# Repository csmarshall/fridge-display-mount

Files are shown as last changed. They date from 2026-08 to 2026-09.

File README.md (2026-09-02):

# fridge-display-mount

One display, one fridge, **three ways to hold up one plate**. A Waveshare 23.8 in FHD touch
monitor on the side panel of a Samsung RS23A500ASR counter-depth refrigerator, running a
household chore board. Parametric generators, validated cut files, and the sheets that explain
every decision, published at <https://csmarshall.github.io/fridge-display-mount/>.

Human-crafted and AI-assisted, human-directed: every dimension, constraint and trade-off here was
reviewed and decided by a human; the code was written with AI as a power tool.

| # | design | page | where in the repo |
|---|---|---|---|
| 1 | **The hook** — a bent plate over the fridge top, held flat by magnets. Finished, quoted, tagged `hook-final` | `hook.html` | repo root |
| 2 | **The clamped strut** — two slotted struts to the floor, clamped top and bottom, no magnets. Standalone fallback | `clamp.html` | `strut/` |
| 3 | **The hook, with optional strut** — design 1's plate cut thinner with four strut holes, so design 2's feet can be bolted on later without recutting. **Being ordered** | `index.html` | `strut/hybrid*.py`; the plate comes from the root generator |
| 4 | **The hook in stock aluminium** — hand-drilled. Validated, cheapest, and **rejected**: not a build the owner wants to do. Kept for the record | `angle.html` | `angle/` |

An engineer's guided read of designs 1 to 3, with the questions we want answered, is `review.html`.

`strut/` was its own repository until 2026-09-02 and was merged here with its history, because
design 3's plate is generated by the root generator and two repos meant two homes for one fact.

## The load path, in one line each

1. The arm **bears** on the fridge top and carries all the weight; the magnets only hold the
   plate flat.
2. The **floor** carries the weight; the clamps hold the struts in; nothing is fixed to the
   building, ever.
3. Design 1 as bought. If it proves too lively, two struts through the plate onto design 2's feet
   and lower clamp, and the magnets come off.

## Quick start

```bash
python3 -m venv .venv && .venv/bin/pip install ezdxf gmsh scikit-fem numpy scipy meshio
.venv/bin/python generate_bracket.py            # design 1: bracket_flat.dxf + preview + params
.venv/bin/python audit_dxf.py                   # acceptance test — run after EVERY generation
( cd strut && ../.venv/bin/python generate_hybrid.py )   # design 3's plate, via the root generator, audited
( cd angle && ../.venv/bin/python angle.py && ../.venv/bin/python angle_sheets.py )   # design 4: validate, templates, sheets
.venv/bin/python console_build.py               # index.html, hook.html, clamp.html, angle.html
.venv/bin/python review_build.py                # review.html, the guided read for an outside engineer
./publish.sh --check                            # everything above plus every sheet; pushes nothing
./publish.sh                                    # same, then push main and gh-pages
```

Every generator **validates before it writes** and exits non-zero having written nothing if any
check fails. That is deliberate: a silently-wrong cut file costs real money.

## What is here

| | |
|---|---|
| `generate_bracket.py` | design 1's generator. Formed dimensions in, flat pattern out. `--strut-bolts` adds design 3's holes |
| `audit_dxf.py` | independent acceptance test against any written DXF and its params JSON |
| `bracket_flat.dxf` | design 1's upload file — mm, layer 0, closed contours, one dashed bend line |
| `strut/dxf/H_hook_plate.dxf` | **design 3's upload file**, made by the root generator, audited |
| `strut/dxf/{A_clamp_bar,B_foot,C_plate,D_backing_strip}.dxf` | design 2's cut parts |
| `plate_fea.py` | finite-element plate check (gmsh + scikit-fem) of the body plate under a touch press |
| `console_build.py` | builds the three pages from one model — decisions, checklist, numbers, prices, every sheet |
| `publish.sh` | rebuild, validate, push `main` and the `gh-pages` branch GitHub Pages serves |
| `docs/` | design 1's brief, price study, review notes, vendor reference drawings |
| `strut/BRIEF.md`, `strut/reference/` | design 2's brief and its evidence (strut channel, SendCutSend PDFs) |
| `CLAUDE.md` | every design invariant, all three designs. Read it before changing anything |

Study scripts (`*_sweep.py`, `*_compare.py`, `*_explainer.py`, `*_study.py`) each answer one
question and write one SVG. `strut/clamp_sheets.py`, `strut/package.py` and
`strut/hybrid_sketch.py` do the same for designs 2 and 3; run them from inside `strut/`.

## House rules that bit us

- **No drifting constants.** If a value is derivable, derive it. Hardcoded numbers here have gone
  stale more than once — a magnet total, a detach table, a pad rule, a bend deduction — each time
  silently.
- **One home per fact.** The magnet height once appeared as 11.5, 12 and 13 mm on three drawings;
  the bend deduction lived in two repos with two values.
- **CLI flags may only turn things off.** `x = not args.no_x` silently overrode dataclass defaults
  and shipped duplicate holes into a cut file.
- **Render it and look at it.** Layout cannot be reasoned about.

## Status

Not yet ordered. Design 3's plate needs a re-quote (the last quote was on an earlier drawing), and
the measurements on the index page's "Before ordering" list are still open. Prices are dated
observations, not derived values.

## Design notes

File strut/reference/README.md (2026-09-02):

# reference/

Everything here is EVIDENCE, not opinion. If a number in the design contradicts something in this
directory, the file wins until someone re-verifies it.

## The appliance

(The Samsung spec sheet and both Waveshare dimension drawings now live once, in
`../../docs/reference/`; the copies that used to be here were byte-identical and were removed on
the 2026-09-02 merge.)

- **`samsung-RS23A500ASR-specsheet.pdf`** — the fridge. Case 35 7/8 × 68 5/8 × 24 in
  (911.2 × **1743.1** × **609.6 mm**), 229 lb, counter-depth. The height that matters is the CASE
  height, not the height over the hinge covers.

## The display

- **`waveshare-23.8-dimension-drawing.jpg`** — the one being mounted. 555.23 × 324.65 × 18 mm
  panel, plus a **25 mm raised rear box** (260 × 134, centred) carrying the VESA 100 pattern, so
  overall depth is 43 mm. 3.94 kg. The Pi 5 fan/GPIO opening is in the rear box FACE at a
  **~82 mm radius** (fan, ~30 dia) and **~107 mm** (GPIO slot), both SCALED off the drawing;
  the hook's windows sit at 87.5, an average — do not blank either off.
- **`waveshare-27-dimension-drawing.jpg`** — the 27 in shares the same rear box, VESA and depth
  profile. Only the panel size and mass differ (629.62 × 367.40, 4.92 kg).

## The strut

- **`strut-channel-3310T791.md`** — the chosen channel, transcribed from McMaster because their
  page renders nothing to a bot. Dimensions, the whole price ladder, and **derived** section
  properties with the assumption that produced them stated.

## The fabricator

- **`sendcutsend-mild-steel.pdf`** — material and thickness range.
- **`sendcutsend-bending-guidelines.pdf`** — bend radius, minimum flange, die width, feature
  keep-out from the bend line. The bent foot lives or dies by this document.
- **`sendcutsend-powder-coating.pdf`** — the 15 colours and the part-size limits. **Textured
  Black** was chosen for the previous design because the fridge's side panel is dark and matte.

## Inherited from the hook design — the reasoning, not the geometry

These four carry work that stays true regardless of load path.

- **`inherited-magnet_primer.pdf`** — why a 175 lb magnet delivers 12 lb where it counts. Pull vs
  shear vs peel, the derate chain, and the arithmetic for what magnet-only would actually need.
  **Read this before resizing the magnets.**
- **`inherited-fastener_matrix.pdf`** — all 39 nut × washer × threadlocker permutations against a
  fixed 1/2 in stud, with part numbers. If the magnet changes, the stud may change and this whole
  sheet has to be recomputed — but the METHOD transfers directly.
- **`inherited-bracket_preview.pdf`** — the plate as built: 310 × 310, VESA 100 plus MIS-E/MIS-F
  spare patterns, vent windows on an 87.5 mm radius, cable slots, magnet holes at 246 mm.
- **`inherited-channel_concept.pdf`** — the concept sheet that led to this project, including the
  wedge arithmetic and the numbers the strut design starts from.
- **`inherited-price-study.md`** — the material/thickness price ladder, and why 0.187 in mild
  steel beat aluminium and stainless.
- **`inherited-hook-BOM.md`** — the previous BOM, with sourced part numbers for magnets, nuts,
  washers, threadlocker and foam. Several lines transfer unchanged; the magnet line is the one
  deliberately being revisited.

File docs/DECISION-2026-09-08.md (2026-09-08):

# Decision — 2026-09-08: order design 3, phase 1, today

Charles: "I really want to get this built, but I am tired of fighting this, I need a comprehensive
review and decision today." This is that review and that decision. Everything below is on the
published sheets; nothing here is a new number.

## The decision

**Order the hook plate at 0.119 in with the strut holes (design 3, phase 1) from SendCutSend, and
eight K&J MM-C-32 magnets. Nothing else is cut. No struts, no clamp parts, no floor hardware.**

| line | what | price | source |
|---|---|---|---|
| plate | `strut/dxf/H_hook_plate.dxf`, A36/1008 0.119 in CRS, 1 bend 90 deg, black powder coat | $187.20 | SendCutSend live 2026-09-02 |
| magnets | 8 x K&J MM-C-32, O32 x 8 mm N38, M6 male stud, 75 lb rated | $61.12 | K&J 2026-09-02 |
| hardware | 8 x M6 thin nyloc (DIN 985 low), 8 x M6 fender washer O18, 4 x M4 spacer 10 mm, 4 x M4 low-head screw, 5/16 in neoprene foam strip, VELCRO ONE-WRAP 1/2 in | ~$50, only the VELCRO priced ($31.25) | hardware store / McMaster |
| **phase 1 total** | | **~$280 + display** | `prices.py` |

The strut kit ($207.48) exists as a later add-on through holes already in the plate. Do not buy
it now; the hook is the design, the kit is the insurance.

## Why this and not the others

- **Design 1 (0.187 in):** $10 more, 2.1 kg heavier, and it has no strut holes so the fallback is
  a recut. Its stiffness advantage (0.022 vs 0.085 mm at the screen edge under a 5 lb press) is
  below anything a finger notices. Nothing else differs. `gauge_magnet_matrix.svg`.
- **Design 2 (struts + clamp):** more parts, floor pads, a clamp under the fridge, and a plate
  that shares nothing with the hook. It is the answer only if the hook fails in use, and design 3
  already carries that answer in four holes. `clamp.html`.
- **Design 4 (stock aluminium):** rejected 2026-09-02, hand drilling.
- **Aluminium plate at SendCutSend:** cheaper on the 2026-08-25 cut-only sweep, but flex is 3x
  steel's at the same gauge, no live quote on the real file, and no reason to reopen the material
  when the steel plate is $187.
- **OSH Cut instead of SendCutSend:** $204.26 coated, $17 more. Their standby tier at $60.93 is
  bent and bare, needs the flat regenerated for their bend table, and you keep the coat. Not
  worth a second vendor flow. `vendors.svg`.
- **Other magnets:** 8 x MM-C-32 is the cheapest set to 6x on a 20 lb grab using the eight
  positions the plate has, on every gauge. Bigger magnets only add cost; smaller ones need four
  holes that are not cut. `magnet_economics.svg`, `gauge_magnet_matrix.svg`.

## What is still unmeasured, and why none of it changes the cut file

| item | status | what it affects | how it is closed |
|---|---|---|---|
| hinge-cover window 406 vs 400 mm | two readings | where the arm lands | the plate is not pinned to the case centre; set it 10-20 mm rearward at install. The cover also lifts off. Nothing to recut |
| Pi fan vs vent window, 3.5 mm overlap | scaled off a drawing, +/-5 mm | cooling | windows sit on R87.5 so one covers the fan in every rotation; the 10 mm spacers keep an air channel regardless. Measure the box when the display arrives |
| MM-C-32 stud length | ESTIMATE 10 mm; K&J does not publish it | nut choice only | **order the magnets first**, measure the stud. Stack needs ~8.5 mm (3.0 plate + 1.5 washer + ~4 thin nyloc). Short stud: drop the washer or use a jam nut. The plate hole (O6.5) is right either way |
| M6 part numbers | NOT VERIFIED | nothing | any DIN 985 low nut and DIN 9021 washer in M6 |
| 5/16 in foam | unsourced | pad rule | 7.94 mm against an 8 mm standoff is -0.06, in band. Neoprene sheet or strip, adhesive-backed |
| case height 1743.1 mm | published, not measured | screen height by the same error | irrelevant at +/-10 mm; the neck is cut to the published figure |
| VESA insert depth | unmeasured | M4 screw length | buy screws after the display is in hand |
| PSU wattage | confirm in box | Pi headroom | Mean Well GST90A12 $29.50 if it is 60 W |

The clamp DXFs still need re-upload after the bend-deduction correction. That is phase 2 work
and gates nothing today.

## Order sequence

1. SendCutSend: upload `strut/dxf/H_hook_plate.dxf`, mm, A36/1008 0.119 in CRS, Bending 90 deg
   (the dashed line is read as 1 bend), Deburring, Powder Coating black. $187.20, coated arrival
   about six business days. Longest lead, so first.
2. K&J: 8 x MM-C-32. Measure the stud when they land.
3. Display + PSU if not already bought ($387.01).
4. Hardware after the magnets: nuts, washers, spacers, screws, foam, VELCRO.

## What stays open in the tracker

Issues #1, #2, #3, #5 are hygiene and do not gate the order. #4 is the list above; close its
items as the parts arrive.

## Addendum, same day: exact costs, the gauge question, the magnet band

Charles asked for exact costs, "the cheapest material that can be the thickest and still be powder
coated and bent", and magnets that are "the cheapest but reliably secure", where reliable means
"it takes effort to move it but it's not impossible".

**Exact costs, phase 1, every line priced (`prices.py`, 2026-09-08):**

| line | price | source |
|---|---|---|
| plate, 0.119 in CRS, bent, coated | $187.20 | SendCutSend live |
| 8 x MM-C-32 at the 5-9 break | $58.48 | K&J |
| 8 x M6 A2 jam nyloc | $2.00 | BoltsandNuts |
| 8 x M6 x 18 x 1.7 fender washer | $1.60 | BoltsandNuts |
| 4 x M4 x 16 button head | $0.56 | BoltsandNuts |
| 4 x RAF M0599-4-AL spacer 10 mm | $3.12 | Newark (snippet) |
| 5/16 x 3/4 in x 10 ft neoprene strip | $50.40 | Fix Supply |
| VELCRO ONE-WRAP roll | $31.25 | McMaster |
| **phase 1** | **$334.61** | |

The plate at 0.187 in instead adds $12.70 ($199.90).

**The gauge question (`gauge_magnet_matrix.svg`, live sweep of every bendable gauge on the real file):**
the thickest steel with a published bend spec is 0.187 in HRPO at $199.90, and hot-rolled makes it
CHEAPER than 0.135 in CRS ($235.83). It is 4x stiffer than 0.119 in (0.022 vs 0.085 mm at the screen
edge) for $12.70 and 2.1 kg. Aluminium at 0.100 or 0.125 in is the cheapest bendable, coatable plate
($159) but flexes 2.5-5x more than 0.119 in steel; aluminium at 0.187 in costs $233. The plate with
strut holes was regenerated at 0.187 in (`strut/dxf/H_hook_plate_187.dxf`, audited 15/15, neck 78x,
body 56x). **Recommendation: 0.187 in HRPO with the strut holes, $199.90.** The one cost is the nut
stack: a 10 mm stud with a 4.75 mm plate, 1.7 mm washer and a ~4 mm jam nut is at the limit, and the
K&J drawing gives the stud as 10 +/-2.5 mm. Order the magnets first; if the stud measures short, drop
the washer or use a 3 mm M6 jam nut. Nothing cut changes.

**The magnet band (`removability.svg`):** against estimated human forces (bump 20 lb, one hand 45 lb,
two hands 100 lb), the band is "slide resistance at least 1.5x a bump, lift-off within two hands".
4 x MM-C-32 is under the bump margin (21 lb). 6 x is in the band (slide 32 lb, lift 50 lb). 8 x is in
the band (slide 42 lb, lift 61 lb, 65 lb on the heavier plate). **Recommendation: buy 8, fit 8.** The
35 % derate is the largest unknown and it flatters the magnets; 8 keeps margin against it. If the
mount fights you when repositioning, take two out — a two-minute change, no parts to buy.

**Stud length is now verified:** K&J drawing MM-C-32.pdf, overall 18 mm, body 8 mm, stud 10 +/-2.5 mm.

## FINAL — Charles, 2026-09-08 12:45

**Plate: 0.187 in HRPO with strut holes, $199.90. Magnets: buy 8 x MM-C-32, fit 8.** Phase 1 total
$347.31, every line priced. The design's cut file `strut/dxf/H_hook_plate.dxf` is now that plate
(310 x 738.81 mm flat, 35 holes, 14 windows, audited 15/15). Order sequence unchanged: plate first,
magnets second, measure the stud when they land, then hardware.

## Addendum 2, same day: one vendor

Charles asked whether magnets from both vendors had been compared with shipping. They had not.
Done: K&J MM-C-32 $58.48 + $7 postage against McMaster 3506K64 $76.96 folded into the one McMaster
shipment that already carries the foam, grip sheet and screws. Net about a wash, four orders become
one. **Decided: McMaster only.** The 3506K64 is the same disc and rating; its 5/16 in height matches
the 5/16 in pad exactly and its 3/8 in stud is a read figure, so the nut stack is settled (thin 1/4-20
jam nut 91847A029, no washer). Hole opened to O7.0 for the 1/4 in stud; the plate file regenerated and
audited. Every hook-hardware line is now a McMaster part number read logged in on 2026-09-08.

**The McMaster order:** 8 x 3506K64, 91847A029 jam nuts (100), 92095A194 M4 x 16 button heads (100),
4 x 94469A046 spacers, 93375K431 neoprene 1/4 x 12 x 12 (laminated under the EPDM to make 5/16), 3727T47 crisscross EPDM 1/16 x 12 x 12,
and optionally 1621N71 grip sheet to slide-test against the EPDM. VELCRO from anywhere.

Foam corrected the same afternoon: the 5/16 in strip was $45.63 for a fifth of a roll; a 1/4 in 12 x 12 sheet under the EPDM skin makes the same 7.94 mm for $23.87.

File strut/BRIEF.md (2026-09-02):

# Fridge-Side Display Mount — STRUT REVISION

Mount a Waveshare 23.8 in FHD touch monitor on the **left side panel** (facing the fridge) of a
Samsung RS23A500ASR counter-depth side-by-side, at a comfortable standing touch height, to run a
household chore board.

**This supersedes a completed hook design.** That design is finished, validated and quoted — it is
not abandoned for being wrong. It is superseded because this one is height-adjustable after the
fact, does not depend on the fridge top at all, and puts the load into the floor. The hook repo is
tagged and kept; see "What came before".

---

## 1. The design, as decided

A **frame**, not a bracket:

```
        display  -> plate -> two struts -> bent foot -> FLOOR
                       |          |
                    (VESA)    magnets to the side panel, in PULL
```

- **Two 6 ft slotted struts**, McMaster **3310T791**, black powder-coated low-profile channel,
  running vertically up the side panel at **246 mm centres**.
- **A bent foot** — one manufactured part — that ties both strut bases together, slides under the
  fridge, and is **wedged** so the appliance's own weight bears on it.
- **A plate** across the struts carrying the display on VESA 100.
- **Magnets** through the strut webs onto the side panel.

### The strut orientation is forced, and it is the good one

Flat back against the panel, slots facing the room. It is the only orientation where a magnet can
bear on the channel, and it gives a wide flat bearing. The cost is that the channel's WEAK bending
axis ends up in the pull direction — which does not matter, because the magnets carry that load.

### The plate should bolt on unmodified if it can

The hook design's plate is 310 × 310 with four Ø8.5 magnet holes at **246 mm centres**, which is
exactly the strut spacing, and Ø8.5 clears a 5/16 channel bolt. Reusing it unchanged is the
cheapest good outcome. **Verify this rather than assuming it** — the previous plate's holes were
sized for a magnet stud, not a channel bolt, and the loads are different now.

---

## 2. What is settled, and the numbers behind it

All computed against a 5 lb press at the screen centre (1331 mm), which is the governing everyday
load — not the display's weight.

| | |
|---|---|
| Overturning at the base | 29.6 N·m |
| Foot strength, 310 mm wide, 0.187 in | 25 MPa vs 248 yield — **SF 10** |
| Strut strength, pull direction | 41 MPa — **SF 6.1** |
| Torsion, edge press, over 246 mm spacing | **3.3 lb per strut** |
| Magnets propping at screen height | **5 lb of PULL shared over 4** — 1.25 lb each |
| Sway if the magnets were absent | **4.7 mm** at the screen |

**The magnets provide STIFFNESS, the foot provides STABILITY, and they are not interchangeable.**
Tying the strut bases does nothing for sway, because the pull load is out of the frame's plane.

### The wedge

The foot slides under the fridge and is wedged (wood shims or similar) so appliance weight lands
on it. What that has to achieve:

| wedge inboard | weight needed on the foot | as a share of the fridge |
|---|---|---|
| 100 mm | 66.6 lb | 29 % |
| 150 mm | 44.4 lb | 19 % |
| **200 mm** | **33.3 lb** | **15 %** |
| 250 mm | 26.6 lb | 12 % |

It is a modest fraction, and further inboard is cheaper.

**DECIDED 2026-08-29: do not chase that load transfer.** The wedge is driven SNUG only — enough to
close the gap, no more. Nothing is taken off the fridge's levelling legs and nothing presses hard
on a base pan that was not designed for a point load.

**This changes what the foot is for, and it is a better answer.** A snug wedge does not anchor by
weight; it removes the slack so the tail is CAPTURED. If the frame tries to tip, the tail can only
rise by the wedge clearance before it bears on the underside of the appliance — tipping is arrested
**geometrically**, by a positive stop, not by friction or by transferred weight. That is a
mechanism you can design and inspect, where "how hard someone drove a wedge" is not.

The magnets still carry the working case on their own, in pull, at roughly 49×. The captured tail
is what stops a lurch becoming a topple.

---

## 3. Open — must be resolved on the actual appliance

**Measured 2026-08-29, roughly:** the gap under the side is **10–20 mm**, and **the underside is
NOT flat**. Both change the design — see §3b.

**Still open — need the appliance:**

1. **Whether a 150–250 mm tail fouls anything.** The irregular underside that gives the pad
   something to bear on also gives the tail something to hit: compressor, tubing, insulation,
   cross-members. This sets the tail depth and nothing else can.
2. **Whether there is a downward-facing rib or lip within reach.** If there is, HOOKING it beats
   bearing on it, because a hook has no compliance at all.

**Answered 2026-08-29:**

3. **Wedge pressure — SNUG ONLY.** See above. The foot captures the tail; it does not transfer
   load. Nothing comes off the levelling legs.
4. **Floor — wood, flat enough.** **No levelling adjustment** — the foot stays a simple bent part.
   But it gets a **pad underneath**, and the reason is not the pressure: at under 3 psi nothing is
   being crushed. It is that the foot's **laser-cut edges line-load a floor that is not perfectly
   flat**, that any grit trapped beneath turns the foot into an abrasive, and that this assembly
   sits unmoved for years rather than being shuffled about.

   **The pad has to GRIP as well as protect**, which rules out the obvious choice. Felt is the
   standard furniture answer and it is wrong here — it would let the assembly slide, which is the
   one thing it must not do. Wants a non-marking rubber or EPDM. **Flag:** rubber left in contact
   with a polyurethane wood finish for years can discolour it through plasticizer migration, so
   the compound matters. Not yet sourced.
5. **Pull-out — rare, treat it as a teardown.** Moving the fridge means unwedging and re-seating.
   That permits a deeper tail and a properly fitted wedge rather than something designed to slide
   in and out, and it means the wedge can be shaped for the gap rather than generic.

---

## 3a. CLAMP the struts to the fridge — decided 2026-08-29

Two adjustable L brackets, one near the top of the struts and one near the bottom, each reaching
from the strut onto the fridge with **foam on the face that touches the appliance**. Slide them
along the strut slots until both are engaged, then lock. The struts are then positively clamped
against the side panel.

**This is the strongest version of the design so far, and it is mostly free.**

### What the top bracket actually has to do

It is a RETENTION bracket, not a hook. The foot already carries the weight.

| clamp height | force to hold the top in |
|---|---|
| at the fridge top (1743 mm) | **3.8 lb** |
| lower, at 1500 mm | 4.4 lb |
| lower still, 1200 mm | 5.5 lb |

Compare the hook design's arm, which carried the **entire 24.9 lb** hanging weight, bore on a
sponge pad, and needed a **180 mm reach** purely to land magnets on metal. This bracket carries
nothing. Its reach only has to be enough not to slip off — tens of millimetres.

### What that buys

- **Anti-tip becomes positive and mechanical.** No longer a magnetic duty. The "what if a magnet
  peels" failure mode goes away.
- **The magnets drop to anti-rattle, or go entirely.** They were carrying 5 lb of pull; the clamp
  now does that. At $23.92 each that is **up to $191 off the BOM** — the largest line in it.
- **The hinge cover stops mattering.** A tens-of-mm reach at the rear of a 406 mm clear window is
  not a clearance problem the way a 180 mm arm was.
- **The slots ARE the adjustment.** A 6 ft strut is 1829 mm against a 1743 mm fridge, so it
  already stands 86 mm proud — the top bracket has somewhere to live without extending anything,
  and the clamp is made by sliding the lower bracket up until snug and locking it.

### What it costs

It reintroduces a fridge-top interface, which §1 had listed as something this design escaped.
That is a real give-back — but a light retention bracket with a short reach is a much smaller
commitment than an arm carrying the whole load, and the clear-window measurement that made the
hook work is already in hand.

### The two clamp brackets are ONE part, made twice

Top and bottom are the same L, the lower one flipped. Foam goes on the same face of the part in
both cases — facing down onto the fridge top, facing up against its underside. One DXF, one part
number, quantity two.

Size the part for the BOTTOM's constraint, which is the strict one: it has to enter a 10–20 mm
irregular gap. The top merely rests on a surface and has a 406 mm clear window to live in, so it
is never the binding case.

### The foot and the lower clamp must be SEPARATE parts

They point opposite ways off the same strut — foot outward onto the floor, clamp inward under the
appliance — so they do not conflict. But they cannot be one part, and the reason is mechanical
rather than aesthetic:

**The lower clamp has to slide UP the slot to generate clamp force. The foot has to stay on the
floor.** Combine them and tightening the clamp lifts the foot off the ground, which destroys the
load path you built the foot for.

### Sizing the foot, now that the clamp exists

If the foot had to resist tipping alone, by reaching out into the room:

| outward reach | SF |
|---|---|
| 200 mm | 1.04 |
| 250 mm | 1.30 |
| 300 mm | **1.56** |

About 300 mm gets there unaided — and that is a lot of steel on a kitchen floor, right where
someone walks.

**The clamp removes that requirement.** With anti-tip handled at the top for 3.8 lb, the foot only
has to carry 154 N downward and not rock. Size it for bearing and for not wobbling underfoot, not
for tipping — which means it can be modest, and stay out of the way.

### Open on this

- **How the brackets generate clamp force.** Sliding the lower one up the slot until snug needs no
  extra parts, but it wants drawing before it is believed — this is exactly the kind of thing that
  reads fine in prose and turns out to need a jacking feature once it is drawn.
- **What the bottom bracket engages.** Same 10–20 mm irregular gap as the foot, so probably the
  same conforming-pad answer in a second place.
- **Whether the identical-part idea survives contact with both reaches.** If the bottom is limited
  by fouling and the top by nothing, one length may be wrong for one of them.

---

## 3c. THE ASSEMBLY — decided 2026-08-31

**Two parts, two of each.**

**Part A — the studded clamp (×2, the lower one flipped).** An L: the long leg lies on the fridge
top, or reaches under its base. The short leg runs down (or up) the side. An **ELEVATOR bolt**
through a square hole in the short leg gives the stud — its square shoulder locks in the laser-cut
hole so it cannot spin, which means the bracket stays a pure laser-plus-one-bend part with no
welding and no secondary operation.

**Elevator, not carriage, because the head faces the FRIDGE.** 5/16"-18 elevator: head 30.16 mm
diameter x **2.78 mm** thick and FLAT, against a carriage bolt's 19.81 mm x 5.08 mm dome. At 2.78
the head **hides inside the 3 mm foam and never touches the panel**; a carriage dome stands
**2.08 mm proud** of the same foam and presses a hard point on appliance sheet. It also spreads
over 715 mm2 instead of 308 — 2.3x the bearing.

The square neck is 8.38 mm across x 4.83 mm long, so it passes **1.80 mm beyond** a 3.02 mm clamp
leg: **the foot's slot has to clear 8.38 mm, not just the 7.94 mm shank.**

**The nut goes INSIDE the channel, bearing on the strut's back web.** The slots are in that web,
so the bolt passes clamp 3.02 + foot 3.02 + web 1.78 = **7.83 mm of material**, plus the nut. A
3/4 in bolt would do; 1 in is comfortable.

Running the bolt clean through the channel and nutting it outside the open face would be a much
longer bolt for no reason, and it would put the nut exactly where the **plate's channel nuts have
to live**. The open face stays clear. Foam lines the inside of the L; no steel touches the appliance
anywhere.

**Part B — the slotted foot (×2, one per strut).** Vertical leg carrying an elongated slot for the
stud; horizontal leg bending **outward, into the room**, tucking under the strut so the strut
stands on it. It therefore never touches the floor and needs no separate floor pad.

**REVISED 2026-08-31: one foot per strut, not two back to back.** The inboard foot was removed
because it was doing nothing the rest of the assembly was not already doing:

| what it might have done | what actually does it |
|---|---|
| resist tipping outward | the outboard foot |
| resist tipping inward | **the fridge** — it is right there |
| anti-lift under the appliance | the lower CLAMP, which was always its job |

Removing it takes one layer out of the stud stack: the gap drops 12.07 → **9.05 mm**, the display
face comes in to **75.7 mm**, and the top washers halve from 6.05 to **3.02 mm**.

### The stack through the stud, and the washers that make it work

At the base the stud passes clamp leg + foot leg = **6.05 mm** before it reaches the strut. Left
alone that would stand the strut off at the bottom and hard against the panel at the top, so it
would lean.

**Fix: 3.02 mm of washers behind the strut at the top**, replacing the foot leg that is not there.
The strut then sits **~9 mm off the panel, parallel, top and bottom** — and nothing but foam ever
touches the appliance.

### How far the display ends up sticking out

66.7 mm of it is fixed no matter what — strut 20.64 + plate + 25 mm rear box + 18 mm panel. Only
the gap is a variable:

| | gap | display face off the panel |
|---|---|---|
| two feet back to back | 12.07 mm | 78.7 mm |
| **one foot, as built** | **9.05 mm** | **75.7 mm** |
| feet outboard of the strut entirely | 6.02 mm | 72.7 mm |

Standard-height channel instead of low-profile would add **20.6 mm** on top of any of these, which
is why low-profile is a requirement and not a preference. Everything here is well inside the
117 mm the doors project.

### Assembly sequence

1. Bolt the two feet back to back, slots aligned, and stand the struts on the outboard legs.
2. Hook the top clamps over the fridge top; stud through washers and the strut slot; nut loose.
3. Slide the lower clamps **up** their slots until they engage under the appliance; lock.
4. Tighten the top nuts. The struts go into tension between the clamps and the fridge is gripped.

### Sliding along the panel — SOLVED by geometry, not friction

Friction alone gives roughly **15–30 lb** of resistance (foot plus preloaded clamps). Enough for
ordinary use, but not positive location.

**Use the clear window instead.** The hinge cover occupies the front 203 mm of the fridge top and
the measured clear window behind it is **406 mm**. Size the top clamp's long leg to very nearly
fill that window and it is captured front-to-back between the hinge cover and the rear edge — a
geometric stop, using a measurement already in hand, needing no extra feature and no second bend.

---

## 3b. The foot, after the gap was measured

**10–20 mm, and not flat.** Two consequences.

### The wedge is the wrong device — use a conforming pad

A wedge bears on unknown high points of an irregular surface, and at the tight end of the range a
0.187 in foot leaves only 5.25 mm for it, which is a fragile shim needing per-location fitting.

**Use a foam pad on top of the tail instead.** It conforms to whatever is up there, which is
precisely the problem, and it needs no fitting. The obvious objection — that foam is a spring and
therefore not a stop — does not survive the arithmetic. The force is small and the area is large:

| pad | thickness | squash under a tip load | screen movement |
|---|---|---|---|
| 60 × 200 mm | 10 mm | 0.37 mm | **2.5 mm** |
| 80 × 250 mm | 10 mm | 0.22 mm | 1.5 mm |

At design loads it barely moves. It behaves as a stop.

### The one real trap is PRELOAD, and it is a big one

Area multiplies pressure. On a 60 × 200 mm pad of the project's 12-psi-at-25 % neoprene:

| compressed | force pushing UP on the fridge |
|---|---|
| 2 % | 18 lb |
| 10 % | 89 lb |
| 25 % | **223 lb — half the appliance** |
| 50 % | 446 lb — you are lifting it |

**Size the pad to JUST TOUCH.** Do not squeeze it in. Fit it by building up layers until contact,
which is acceptable because moving the fridge is a teardown anyway. Half a percent of strain is
0.3 mm of screen movement — the job needs nothing more than contact.

### Foot thickness: go thinner than the hook's

The foot only sees the full moment as a BACKSTOP, so it does not need SF 10.

| | | |
|---|---|---|
| 0.187 in | SF 9.8 | only 5.25 mm of pad room in a 10 mm gap |
| **0.119 in** | **SF 4.0** | **6.98 mm of pad room** |
| 0.075 in | SF 1.6 | too thin |

**0.119 in** is the balance. Threaded jacking screws were considered and rejected: precise and
adjustable, but they bear on a point of an irregular surface, and conformity is worth more here
than adjustability. Keep them in mind only if a genuinely rigid stop is ever wanted.

---

## 4. The magnet decision — deliberately reopened

The hook design used McMaster **3506K67**: Ø48.02 × 11.51 mm, 175 lb rated, **$23.92 each**, eight
of them — **$191, the largest line in the BOM**.

In this design the demand is **1.25 lb per magnet against 61.2 lb of derated capacity — 49×**.
That is heavily over-specified. **Resize it.** Constraints to respect:

- Derate to **~35 %** of rated pull on 0.6–0.9 mm painted appliance sheet. Vendor ratings assume
  thick steel at zero gap and neither holds here.
- The magnet body height IS the standoff, and it must clear the strut wall (1.78 mm) with enough
  stud left for a nut inside the channel.
- Keeping a **5/16"-18 male stud** would let the whole fastener analysis carry over unchanged
  (`reference/inherited-fastener_matrix.pdf`). A different thread means redoing it.
- Read `reference/inherited-magnet_primer.pdf` first. The physics of why ratings mislead is
  already worked out and it does not need redoing.

---

## 5. Deliverables

Match the previous project's shape — it worked:

| | |
|---|---|
| `generate_foot.py` | parametric generator for the bent foot. Formed dimensions in, flat pattern derived by subtracting the bend deduction. **Validates, then writes; exits non-zero and writes NOTHING on failure.** |
| `foot_flat.dxf` | the upload file. mm, layer 0, closed contours, one dashed bend line |
| `foot_params.json` | machine-readable expected geometry |
| `audit_dxf.py` | acceptance test, run after every generation (copied in, needs re-pointing) |
| `assembly_*.svg` | how it goes together |
| `SENDCUTSEND-ORDER.md` | order config, hole schedule GENERATED from the params, compliance table |
| `BOM.md` | sourced, with part numbers and dates |
| `index.html` | the console page, via `console_build.py` |

---

## 6. Hard-won lessons from the previous project

These cost real time. Do not rediscover them.

- **Never hand-maintain a table that the generator could emit.** The previous order document's
  hole schedule drifted a whole revision and described screws into a thread that did not exist.
- **A flag may only turn something OFF.** Argparse defaults silently overrode dataclass values
  five separate times, once putting duplicate holes 0.02 mm apart into a cut file.
- **Filter `spare` when counting magnets.** Counting holes as fitted magnets produced wrong force
  figures on four different sheets.
- **SVG is XML.** Text emitters must escape `&`, `<`, `>` — one bare `<=` silently destroyed a
  whole document.
- **Emit every leader, rule and dimension BEFORE any text that has to survive them.** The same
  z-order bug appeared in four different sheets; a halo behind text is useless if geometry is
  painted over it afterwards.
- **Derive positions, never fix two things that must stay clear of each other.** Fixing one and
  moving the other into it happened repeatedly.
- **Colour follows the BACKGROUND, not the subject.** The fridge is near-black; anything drawn on
  it needs the light palette, and anything drawn on paper does not.
- **Render and look. Do not reason about layout.** Three consecutive fix passes each repaired
  defects and introduced new ones; only rendering caught it.
- **State provenance.** Mark every number as measured, derived, or estimated. A vendor figure and
  a guess must not wear the same font.

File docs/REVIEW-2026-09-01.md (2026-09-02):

# Project review and gap analysis — 2026-09-01

Scope: both repos (`fridge-display-mount`, the published page, and `fridge-strut-mount`, the
clamp/hybrid generator), read top to bottom against `CLAUDE.md`, `BRIEF.md`, `session-state.md`
and the 2026-08-27 review. Everything below was checked by running it, not by reading prose.

## What was verified working

| Check | Result |
|---|---|
| `generate_bracket.py` + `audit_dxf.py` (hook) | 0 errors, 4 warnings; audit 15/15 ACCEPT |
| All 20 study/sheet scripts in the pages repo | every one exits 0 and reproduces its committed SVG byte-for-byte |
| All 7 scripts in the strut repo | exit 0, SVGs reproduce byte-for-byte |
| 2026-08-27 review items A1–A4, C1–C4, D1–D5 | all closed (order doc rebuilt, BOM item 1 on $197.07, CLAUDE.md §4b/§5/§1.5 fixed, washer 0.060 justified in source, `mu_rubber` renamed, 27in drawing regenerated) |
| `hook-final` tag | present |
| GitHub Pages | live at csmarshall.github.io/fridge-display-mount, built from `gh-pages` |

DXF regeneration is non-deterministic (handles and timestamps), so a DXF diff is never evidence
of a geometry change. The audit is the only test.

## Gaps, ranked

### 1. The published page says the opposite of the current decision
`index.html` "What is being built": *"CURRENT — a clamped strut … there are NO MAGNETS … Work
continues in fridge-strut-mount."* Session state 2026-09-01: the hook is **primary again**, the
clamped strut is the fallback, and a third design (hook plate prepared for struts) is what will
be ordered. Neither `index.html` nor `archive.html` mentions the third design at all (grep for
third/hybrid/contingency: 0 hits in both). `hybrid_overview.svg` / `hybrid_sketch.svg` are
committed but not registered in `console_build.py`. `gh-pages` is at 08-31 18:23, one
decision behind.

### 2. The hybrid plate is 0.119 in, and the reason recorded for that is false in phase 1
`hybrid.py:41`: `plate_t = 0.119 * IN  # was .187 HRPO; the feet take load off the plate`.
The first order is the hook plate ALONE with no feet; the feet are bought only if the arm is too
lively. So in the configuration actually being ordered, a 0.119 in plate carries the full hook
load — the case the hook design settled on 0.187 in for (`thickness_study`, PRICE-STUDY: 0.14 mm
deflection, "feels rigid"). `hybrid.py` has **no stress or deflection check at all**; the hook
generator's neck/body SF checks were not carried over. Strength is almost certainly fine (SF
~25x by t² scaling from the 0.187 figures) but touch-press stiffness drops ~4x (t³) and nobody
has computed it. Either re-run the thickness reasoning at 0.119 and record the result, or go
back to 0.187 and re-quote.

### 3. The strut repo's cut files have no acceptance test
Five DXFs in `dxf/` and `audit_dxf.py` cannot run against any of them: it requires an
expectations JSON and none is written (`generate_parts.py` / `generate_hybrid.py` never emit
one; no `*.json` exists in the repo). BRIEF §5 lists `foot_params.json` and "audit_dxf.py …
needs re-pointing" as deliverables; neither happened. Session state's "audits clean" for
`H_hook_plate.dxf` was an ad-hoc run that cannot be repeated. This repo's own README says a
silently wrong cut file costs real money; the strut repo has exactly that exposure.

### 4. Four generator warnings nobody has acknowledged
`magnet_window_overlap`: all four body magnet discs overlap their vent window by **11.51 mm**
("the magnet face would sit over a hole"). Not mentioned in CLAUDE.md, the order doc, the BOM
or the page. Either it is accepted (magnet face bridges the window, foam still bears) and should
be written down as a decision, or the windows should move. The hook page currently shows the
part as validated without saying it carries warnings.

### 5. Stale text on the CURRENT page's "Before ordering"
- "406 mm clear … against a **190 mm arm width**" — hook text on the clamp page (no arm exists).
- "Pi fan opening is at R87.5 mm" — superseded 08-31 by the two-feature reading (fan ~R82,
  GPIO slot ~R107) that CLAUDE.md records; the page still carries the averaged figure that
  CLAUDE.md explicitly says "hid that the fan is the near one". `reference/README.md` in the
  strut repo says 87.5 too.
- Hinge cover: commit b023977 says "measured at 209.55", CLAUDE.md says "front 203 mm". One
  home per fact — pick one.
- `archive.html` still captions the thickness study "SUPERSEDED" (it is the current build's
  study, aluminium-era caption) — B2/B5 from the last review, half-fixed.

### 6. Documents that describe a repo that no longer exists
- `README.md` title `# fridge-magnet-mount`; says `console_build.py` builds `index.html` as
  "the working surface" (it now builds the clamp page and `archive.html` for the hook); "Four
  measurements gate it" (the page lists three open, one blocked); no mention of the strut repo,
  the archive page, the tag, or how `gh-pages` is published.
- `fridge-strut-mount/START-HERE.md` points at `csmarshall/fridge-magnet-mount` (renamed).
- `fridge-strut-mount/console_build.py` is a stale copy importing a module that is not there
  (session state already says ignore it — delete it).
- `channel_concept.py` writes `channel_concept.svg`, which is untracked and unused (the page uses
  `strut_concept.svg`). Dead script or missing commit.
- `docs/.REVIEW-2026-08-27.md.swp` — vim swap file on disk.

### 7. Process gaps
- **Zero GitHub issues** in either repo. The `feature:/bug:/chore:` queue convention has
  never been exercised here; every loose end lives only in the gitignored session-state.
- **Both repos have one unpushed commit** (c81b898, 67228cf). Pages is manually published
  (no workflow, no script, not documented) and is behind main by one publish.
- **Bend deduction is still K = 0.42 estimate**, not SendCutSend's calculator value, across
  all three designs. CLAUDE.md §4 has said "replace" since 08-24.
- **Six BOM lines in the clamp design are NOT PRICED**; the backing strips cannot be powder
  coated at 20 mm and would be the only bare steel; fit-or-not undecided.
- **The hybrid's strut overlap is luck** (43 mm at exactly 4 ft), already flagged in session
  state but not guarded by an assertion in `hybrid.py` the way `magnet_to_bolt` is.

### 8. Measurements still open before any order
From the page and the briefs, unchanged for a week:
1. Height to the top of the CASE (design assumes Samsung's published 1743 mm) — blocked.
2. Photograph the display's rear box: fan opening position and size (scaled ±5 mm; now gates
   the plate in the clamp design).
3. VESA insert thread depth (sets M4 length).
4. Top corner radius (confirmation only; pad covers to R35).
5. Under the fridge: does a 150–250 mm tail foul anything; is there a rib to hook (clamp design
   only, needs a torch).
6. Bundled PSU wattage vs the 63 W budget (CLAUDE.md §5) — still "confirm in box".

## What I did not change
Nothing in either repo was modified. Generated files were regenerated to check reproducibility
and restored with `git checkout`. The one untracked file I produced (`channel_concept.svg`) was
deleted.

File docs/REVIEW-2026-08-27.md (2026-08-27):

# Package review — 2026-08-27

Four independent reviews (numeric consistency, narrative consistency, visual defects, plus the
magnet-primer build). Findings below are **deduped and merged**; "×2" means two reviewers found
it independently, which raises confidence.

Nothing in this file has been fixed yet unless marked FIXED.

---

## A. Critical — documents that would cause a wrong order

| # | Finding | Where |
|---|---|---|
| A1 ×2 | **The order document is entirely on the superseded 0.119" build.** Thickness, bend deduction (0.1955" vs current 8.19 mm), blanks 687/737, neck 262, spacing 250×240, "two arm magnets", cut ~$87. It also still describes **magnet screws into a female thread** — the magnet is now a male-stud part with no screws at all — and gives the standoff as both "6 mm" and "8 mm" in one section when it is 11.51 mm. It references a file `..._neck260.dxf` that does not exist. | `SENDCUTSEND-ORDER.md` |
| A2 ×2 | **BOM item 1 orders a part that no longer exists**, at 0.119", blank 310×742, **$185.54**, with "4 countersinks" — contradicting this same file's own correction banner and `countersink_vesa: false`. Marked **VERIFIED**. | `docs/BOM.md:21` |
| A3 | **Three prices in circulation for "the bracket":** $185.54 (BOM), $185.85 (CLAUDE.md, 0.119 build), $197.07 (session-state, the only one quoted on the .188 part at the current blank). | multiple |
| A4 | **BOM "fitted now" subtotal is $9.60 out** — printed $928.73, the lines sum to $938.33. | `docs/BOM.md` |

## B. Contradictions visible on the published page

| # | Finding | Where |
|---|---|---|
| B1 ×2 | **Two pull-off numbers for the same grab: 178 lbf and 146 lbf.** A comment in the source already says this was reconciled to one model — it wasn't; the page still shows both. | `index.html`, `console_build.py:180` |
| B2 ×2 | **Both sweeps captioned "SUPERSEDED"** — the two I rebuilt today on corrected Samsung numbers. The ergonomics caption is also garbled ("it the built neck (257) is not among its panels") and the arm-width one prints "610 mm" twice where the second should be the window measurement. | `console_build.py` |
| B3 ×2 | **"all six are fitted"** — a fossil of the 4-body + 2-arm era. Eight are fitted, stated correctly two cards earlier on the same page. | `index.html` |
| B4 ×2 | **Live-prices table is the 2026-08-25 / 0.119-era quote**, on the page that declares .188 settled. The .188 re-quote appears nowhere. The vents, lightening and reach cards all reason from the $96.70 part. | `index.html` |
| B5 ×2 | **thickness_study caption is one supersession behind** — "the build is A36 steel 0.119 in at 3.71 kg". | `index.html` |
| B6 | **"216 mm to spare (2.14×)" vs "6.6 mm of clear air."** Both true of different things — total window vs the as-derived centred placement — but the 2.14× framing overstates the real installed margin by ~30×. | `index.html`, `hinge_clearance.svg` |
| B7 | **"inset 30" and "12 mm of plate beyond every disc"** vs built inset 32, which leaves **7.99 mm**. | `console_build.py:196` |

## C. The instruction file contradicts the build

`CLAUDE.md` is the file every agent is told to trust, so its errors propagate.

- **C1 ×2 — §5 forbids the magnet actually specified:** "Not male-stud — a stud needs a nut on the
  display-facing side and breaks the flat mounting plane." The build is 3506K67, a **male stud**,
  secured by exactly that nut. The BOM asserts the opposite doctrine ("male-stud style is
  load-bearing"). One of these must go.
- **C2 ×2 — §4b "settled geometry" is stale on nearly every number:** spacing 250×240 (built 246),
  neck 310 (built 257), blank 742 (738.8), quote $185.85 ($197.07), arm rows "90 and 144" (fitted
  are 36 and 144), plus a whole countersink paragraph that is retracted elsewhere.
- **C3 ×2 — §1.5 contradicts itself in one paragraph:** "Validator bound is now −0.60 to +0.30 mm"
  then "the validator accepts 0 to +1.0 mm and rejects anything negative." The code implements the
  first. The second is un-deleted old rationale.
- **C4 — §3 still says "0.119" as built"**; §4 says orientation landscape, built is portrait;
  §1.1 says μ 0.7 rubber-faced, the code uses 0.2 bare nickel.

## D. Real numeric bugs (not just stale prose)

- **D1 — Washer max thickness is wrong in the generator.** `WASHERS` carries **0.060 in**; the
  verified McMaster range max is **0.069 in**. Consequence: the published row "thin nyloc + washer
  fits (+0.08 mm)" actually becomes **−0.15 mm, does not fit**. The specified jam-nut stack still
  fits at 0.069 (+1.44 mm), so **the order is safe** — but the fit table is computed on the wrong
  number, and 0.069 is the figure the decision was actually made on.
- **D2 — `mu_rubber` holds 0.2, not 0.7**, with a comment saying it is not rubber any more.
  `magnet_shear_rubber_lbf` and `magnet_shear_bare_nickel_lbf` are now identical duplicates in the
  report. One home per fact says: rename and drop the duplicate.
- **D3 — Upcharge is +$11.21, not +$11.71** (PRICE-STUDY ladder: $177.00 → $188.21). Digit swap.
- **D4 — `assembly_drawing_27in.svg` was never regenerated** after the thickness change; it still
  says 0.119 in / 3.02 mm while its 23.8" sibling says 0.187/4.75. The page links both.
- **D5 — 0.187 vs 0.188** for the same thickness. Both appear, sometimes on one page.
- **D6 — Foam: 11.5 mm modelled, 7/16" (11.11 mm) purchased.** 11.11 passes the validator, so this
  may be a deliberate imperial substitution, but nothing reconciles the two numbers.
- **D7 — `magnet_pattern_study` panel 3:** the second-row discs overlap the corner discs by roughly
  half a diameter. At the stated 54 mm row pitch Ø48 discs should nearly touch, not overlap.
  **Possible data bug rather than a drawing bug** — verify the pitch before restyling.

## E. Visual defects (all CONFIRMED by rendering)

| Sheet | Defect |
|---|---|
| `stack_detail` | "Runner-up…" line escapes the green box and is **clipped at the canvas edge**. Long panel titles **collide with the slack badge** ("…washer O1.2**60.32** mm"). |
| `fastener_matrix` | Section headers overlapped their own count ("FITS — 1**t** least…"). **FIXED** — my earlier fix measured the title but not the appended count. |
| `approval_sheet` | Caption text drawn **behind** the 3D fridge, grey-on-grey and unreadable. A rotated "door" label clipped to "do…". Panel-2 header crowding; "hinge cover / lifts off" struck through by a dimension line. |
| `crown_explainer` | Middle panel sits ~45 px high, overlapping the section-2 header; small "arm" captions land on the panel titles; "FOAM fills this wedge" struck through by the arm line. |
| `bracket_preview` | Right sidebar note clipped at canvas edge ("…the 11.51 mm mag\|"). Every optional disc reads "OPT◯NAL" — the centre hole sits on the text. |
| `ergonomics_sweep` | The gold 6'4" eye-line runs at the same y as all four "screen centre" labels, reading as **strikethrough on every panel**. |
| `orientation_compare` | "arm 190 mm" stacked directly on "hinge cover, 37 mm proud" in both panels. Red "into the door's path" collides with the green comfort pill. |
| `magnet_pattern_study` | Panel 2 subtitle overflows into panel 3's ("pa**co**th**rners**"). Plus D7 above. |
| `assembly_drawing_27in` | "DISPLAY 367.40" dimension drawn **under the black title bar**. |
| `assembly_drawing` (both) | Pi-fan label runs across the dashed rear-box outline. Bottom ~35% of canvas empty. |
| `harness_view` | Green label sits on a magnet disc; "NECK" has slot geometry through the letters; the **identical FAIL line prints twice**. |
| `force_table` | Green highlight column overruns the table by ~90 px. |
| `variants/*.svg` | 12 stale renders of an older, worse layout — legend collides with the elevation. Regenerating would fix wholesale. |

**Clean:** `spacing_explainer`, `thickness_study`, `variant_compare`, `arm_width_sweep`,
`hinge_clearance`, `mount_views`, `display_compare`, and the `fastener_matrix` body/footer.

## F. Cross-set inconsistency

- Foam is gold hatch in some sheets, solid amber in others.
- Magnets are pink/magenta everywhere except `magnet_pattern_study`, where "as built" is blue —
  and pink means "fitted" elsewhere.
- Title treatment varies three ways; `hinge_clearance` and `force_table` carry **no REFERENCE ONLY
  banner**, which the rest of the set treats as mandatory — and they are the two sheets most likely
  to be mistaken for authoritative numbers.

---

## Fixed during this pass

- `fastener_matrix` section-header collision (E, above).
- Fridge palette moved to one home in `bracket_common.py` and recoloured to the real appliance:
  near-black charcoal side panel, stainless doors. Was hardcoded pale grey in ten files.
- On-fridge caption contrast in `ergonomics_sweep`.

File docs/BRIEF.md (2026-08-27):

> **SUPERSEDED — historical record, do not build from this.**
> This is the ORIGINAL brief, kept verbatim so the provenance of each decision stays auditable.
> It describes a **different refrigerator**. The build target is a **Samsung RS23A500ASR**
> counter-depth side-by-side: 1743.1 mm to top of case, 609.6 mm deep, top and sides both
> magnetic, top measured FLAT. Every fridge-specific number below has been retracted — see
> `CLAUDE.md` §2 for what carried over and what did not. Material also changed from 5052
> aluminium to 0.188 in mild steel (`docs/PRICE-STUDY.md`).

I'm building a magnetic mount that hangs a 23.8" touchscreen on the side panel of a refrigerator. I want you to build the parametric CAD-generation toolchain and the fabrication package for it.

Work in this repo. Create a CLAUDE.md capturing the design invariants below before you write any code, so they survive compaction.
Hardware
Display: Waveshare 23.8" FHD Monitor (SKU 34025)

555.23 (H) × 324.65 (V) × 18.00 (D) mm
3.94 kg
VESA 100 × 100
12 V input, ≥3 A required to boot, 36 W typical
Aluminium enclosure, optically-bonded toughened glass, 10-point capacitive touch
Raspberry Pi 5 mounts internally; enclosure has reserved airflow vents
Bundled PSU is 12 V 5 A (60 W)
Spec source: https://docs.waveshare.com/23.8inch_FHD_Monitor

Mounting surface: LG side-by-side refrigerator (US model), painted steel side panel, approximately 0.6–0.9 mm sheet over foam insulation. LG side-by-sides use a single formed steel wrapper for both sides and the top, so the top edge is a real sheet-metal bend rather than an assembled joint — expect a corner radius in the 6–15 mm range. Side panels are almost always painted steel even on PrintProof stainless models, so magnetic is the likely outcome — but the build still has to survive a non-magnetic panel (see load path below).

Watch for three LG-specific features when validating fit:

A shallow crown on the top panel (wrappers are often domed for rigidity). A rigid 130 mm arm can rock fore-aft on a crowned surface.
Hinge cover caps at the top front corners.
Cable and waterline routing with a step-down at the rear.

The arm must sit mid-depth, clear of all three.
Design that has already been settled — do not re-litigate these
1. The load path is a hook, not friction. A one-piece bent bracket reaches over the top edge of the fridge. The horizontal ARM rests on the fridge top; the entire vertical load transfers into bearing at the top corner. The VERTICAL SPINE drops down the side panel. Magnets carry zero vertical load.

This matters because magnets are rated for pull on thick steel at zero gap, and neither condition applies. Derate to ~35% of rated on fridge sheet, then multiply by μ (≈0.7 rubber-faced, ≈0.2 bare nickel) to get shear capacity. Vendor data confirms the penalty: totalElement rates a 43 mm rubber pot magnet at 33.5 lb vertical pull but only 7 lb horizontal. Magnet-only mounting would need roughly 15× the display weight in rated pull force. The hook eliminates that entire failure mode and makes the design work even if the panel turns out to be non-magnetic 304 stainless.

2. Touch input is the governing magnet load. Pressing near the outer edge of the screen applies torsion about the vertical spine axis:

M_torsion   = F_press × (screen_width / 2)

F_per_side  = M_torsion / magnet_spacing

A 5 lb press 278 mm from centre = ~55 in·lb. Over a 240 mm magnet spacing that's ~6.1 lbf per side. Over a 60 mm spine it's 23 lbf. The plate must be wide. Treat magnet spacing as a load-bearing dimension and warn loudly if any parameter change shrinks it.

3. Peel is negligible here, but compute it anyway.

T_peel = W × d / H

where d = CG offset from the fridge face and H = magnet-to-bottom-pad distance. The display's 18 mm depth keeps d ≈ 26 mm, so T ≈ 0.84 lbf. Report it; don't design around it.

4. The corner radius mismatch is a solved problem — size the pad, don't chase the radius. Nobody publishes sheet-metal bend radii for appliance cabinets, and you don't need one. Let R_f be the fridge's top corner radius and R_b the bracket's inside bend radius (6.35 mm for 3/16" 5052).

R_f < R_b: bracket flats seat cleanly on the fridge flats, air void at the corner. Ideal — the arm bears across its full width. Sponge fills the void.
R_f > R_b: the bracket rides up on the corner and its flats lift off by

flat_gap = (R_f − R_b) × (1 − 1/√2) ≈ 0.293 × (R_f − R_b)

At R_f = 12 mm that's 1.65 mm; even at an implausible R_f = 20 mm it's 4.0 mm. A 10 mm closed-cell sponge pad absorbs the entire plausible range. Implement flat_gap as a function in the generator, report it across R_f = 3–20 mm, and assert the specified pad thickness covers the worst case with compression to spare. Do not add a second bend or a joggle to chase the radius.

5. Other invariants.

Bottom pad thickness must exactly equal the magnet standoff, or the plate sits skewed.
The arm pad must be closed-cell sponge, thick enough to conform to the fridge's top corner radius. A rigid bracket landing on that folded sheet-metal edge will line-load and crease it.
Do not blank off the display's rear vents with solid plate. A Pi 5 behind an unvented slab will throttle.
A flat plate against a wall is loaded in its weak bending axis. Check it; add ribs or thickness rather than assuming.
Manufacturing target: SendCutSend
Verify all of these against their current published specs before you rely on them — fetch the pages, don't trust my numbers. They change.

Material: 5052-H32, 3/16". Not 6061-T6 — it cracks along tight bends. 5052 is among the most formable aluminums and working stress here is ~500 psi against ~28 ksi yield, so the softer alloy is free.
Effective bend radius after bend for 3/16" 5052: 0.250"
Minimum flat flange length: ~1.150" worst case, required on both sides of the bend line for material ≥0.187"
Dies span 0.472"–1.575"; keep cut features at least half the die width from the bend line
2D uploads: all objects on one layer, no open contours, floating interiors bridged
Bend lines are placed interactively in their browser tool — do not put a bend line in the DXF, it will be rejected
Bend deduction comes from their bending calculator, not from a formula you invented
Deliverables
generate_bracket.py — parametric flat-pattern generator using ezdxf.

Formed (post-bend) dimensions are the inputs; derive the flat by subtracting bend deduction.
Expose neck length, bend deduction, body width/height as CLI args.
Emit rounded corners via LWPOLYLINE bulge values, computed from the turn angle at each vertex — handle convex and reflex corners with the same code path. Sign the bulge from the 2D cross product.
Validate before writing. Check flange lengths both sides, feature clearance from the bend line, hole-to-window edge distance (≥1× thickness), magnet disc overhang past the plate edge. Refuse to write files if a check fails; exit non-zero.

bracket_flat.dxf — the upload file. mm units ($INSUNITS = 4), layer 0 only, every contour closed.

bracket_preview.svg — annotated visual check showing the bend line position, magnet disc footprints, and key dimensions. Clearly marked as reference-only, not for upload.

SENDCUTSEND-ORDER.md — order configuration table, bend setup parameters, hole schedule, constraint-compliance table, a full BOM (bracket, magnets, fasteners, soft goods, electrical), an assembly sequence, and a pre-order measurement checklist for the fridge.

audit_dxf.py — reads the generated DXF back and asserts: single layer, zero open contours, correct units, expected extents, expected hole diameters. This is the acceptance test; run it after every generation.
Suggested starting geometry
Landscape orientation. Body 300 × 300 mm (hides behind the 555 × 325 display), neck 130 mm wide, arm 130 mm from the bend apex. VESA 100 × 100 centred on the body. Four Ø4.5 mm magnet holes inset 30 mm from each body corner. Lightening and ventilation: a Ø90 mm centre opening plus four 100 × 40 mm edge windows.

Derive everything else. If your validation finds a better arrangement, take it — but keep magnet spacing ≥ 240 mm and tell me what changed and why.
Hardware BOM constraints
Magnets: Ø43 × 6 mm rubber-coated neodymium pot magnets with M4 female thread. Not male-stud — a stud needs a nut on the display-facing side, which breaks the flat mounting plane.
Use M4 spacers between plate and display: they clear the magnet-screw heads and open an air channel.
Power: budget 36 W (display) + up to 27 W (Pi 5) = 63 W against the bundled 60 W brick. Flag the upgrade.
Code style
Timestamped logging on every operation. INFO for major steps, DEBUG for per-feature detail (per-corner fillet math, hole positions, validation results). Configurable level via CLI. Consistent format across all modules. Include relevant variable state in DEBUG lines.
Self-documenting names, inline comments only where the logic is non-obvious (the bulge math needs one, the bend deduction derivation needs one).
No dead code, no unused variables, no placeholder stubs — implement everything.
unset TMOUT near the top of any shell script.
Type hints and dataclasses where they earn their keep.
Parameters I still need to measure
Leave these as clearly-marked CLI defaults with a warning in the docs:

Neck length — (fridge top → desired display top edge) − 12 mm. Default 100 mm.
Bend deduction — from SendCutSend's calculator. Estimate from BD = 2 × (R+T)tan(45°) − (π/2)(R + K·T) and state your K assumption.
Orientation — build landscape first, but make portrait reachable by parameter. Portrait is mechanically better (torsion arm drops from 278 mm to 162 mm), so note that in the docs.
Fridge top corner radius — default to a 12 mm assumption. It only affects pad sizing (see invariant 4), never the cut geometry. Document the tangent-point measurement in the order doc: hold a straightedge flat against the side and another flat on the top; they intersect at the theoretical sharp corner; measure from that intersection along the top surface to where the flat stops and the curve begins — for a 90° corner that distance is the radius. Cross-check down the side face. Quick screen: a US quarter is Ø24.26 mm (R = 12.13 mm), so if it rocks and won't seat in the corner, R_f is under 12 mm.

Start by writing CLAUDE.md, then the generator, then the audit script. Show me the rendered preview before you write the order document.

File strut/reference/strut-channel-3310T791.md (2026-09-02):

# Low-Profile Strut Channel — McMaster-Carr

Captured from the McMaster listing 2026-08-29. Their product page is a JavaScript app that
renders nothing to a bot, so a PDF of it is a blank shell — this transcription is the reference.

## The chosen part

**3310T791 — Black Powder-Coated Steel, slotted hole**

Black matters twice over: it matches the fridge's own side panel, and it matches the textured
black powder coat chosen for the steel parts.

| | |
|---|---|
| Height (depth off the panel) | **13/16 in = 20.64 mm** |
| Width (the slotted face) | **1 5/8 in = 41.28 mm** |
| Inside channel width | 7/8 in = 22.23 mm |
| Wall thickness | **0.07 in = 1.78 mm** |
| Slot length | 1 1/8 in = 28.58 mm (drawing says 1.13 in) |
| Slot width | 9/16 in = 14.29 mm (drawing says 0.56 in) |
| **Slot pitch, centre to centre** | **2 in = 50.80 mm** |
| First slot centre from the channel end | 1 in = 25.40 mm |
| Gap between slot ends | 7/8 in = 22.23 mm |
| Slot end to channel end | 7/16 in = 11.11 mm |

McMaster's own caveat, worth keeping in front of you: *"Low-profile is channel not as strong as
standard, but it's the same width, so it fits most of the accessories we offer."*

### Prices by length

| 1 ft | 1.5 ft | 2 ft | 3 ft | 4 ft | 5 ft | 6 ft | 80 in | 8 ft | 10 ft |
|---|---|---|---|---|---|---|---|---|---|
| $6.37 | $9.55 | $12.74 | $19.11 | $25.48 | $30.26 | **$34.40** | $38.86 | $45.86 | $54.15 |

Two 6 ft lengths = **$68.80**.

## The rest of the range, same dimensions

| Material | Wall | Part | 6 ft |
|---|---|---|---|
| Zinc-Plated Steel | 0.08" | 3310T513 | $43.79 |
| **Black Powder-Coated Steel** | **0.07"** | **3310T791** | **$34.40** |
| Green Powder-Coated Steel | 0.07" | 3310T515 | $34.40 |
| White Powder-Coated Steel | 0.07" | 3310T488 | $39.26 |
| Yellow Powder-Coated Steel | 0.07" | 3310T777 | $92.16 |
| Galvanized Steel | 0.08" | 3310T517 | $33.75 |
| 304 Stainless Steel | 0.08" | 33085T93 | $84.73 |
| 316 Stainless Steel | 0.08" | 33085T94 | $116.91 |
| Aluminum | 0.06" | 3230T36 | $30.73 |
| Primed Steel | 0.08" | 3310T514 | $79.59 |

Note the powder-coated and aluminium options are **thinner** than the plated/stainless ones
(0.07 and 0.06 vs 0.08 in). If the section properties ever get re-derived, the finish changes them.

## What the slot pitch means for the clamps — CONFIRMED 2026-08-31

Read off McMaster's own spec table and 2-D drawing, not assumed.

Slots are **50.8 mm on centres** and each is **28.58 mm long**, so there is a 22.23 mm dead zone
between them. A clamp stud can therefore be placed anywhere within about **±11 mm** of any target
height by choosing the right slot, and can then slide 28.58 mm within it.

On a 6 ft strut that is roughly **36 slots**. Ample.

Worked for the top clamp: with the strut standing on a ~3 mm foot leg, slot centres fall at
28.4 mm + n × 50.8. The slot nearest the fridge top (1743.1 mm) is centred at 1704.8 mm and spans
**1690.5–1719.1 mm**, i.e. 24–53 mm below the top surface. A clamp whose short leg drops ~40 mm
lands in it comfortably.

## Section properties — DERIVED, not published

McMaster do not publish I or Z for this profile. These were computed from the dimensions above
with an **estimated 6 mm return lip**, so they carry that estimate's error. Recompute if the lip
is ever measured on the real part.

Bending about the axis that resists a push away from the panel (the weak direction, because the
flat back must face the fridge for the magnets to bear on it):

| | |
|---|---|
| Area | 162 mm² |
| I | **9,334 mm⁴** |
| Z | **719 mm³** |
| Mass | 1.27 kg/m → 2.32 kg per 6 ft length |

## Why the orientation is forced

The flat back must face the fridge: it is the only surface that can bear a Ø48 magnet, and the
magnet's 5/16"-18 stud passes through the 1.78 mm web into a channel nut inside. Turn the channel
90° and only an edge touches the appliance.

That forces the **weak** bending axis into the pull direction. It does not matter, because the
magnets carry that load rather than the strut — but it is why the sway numbers look poor if you
ever analyse the strut as an unpropped cantilever.

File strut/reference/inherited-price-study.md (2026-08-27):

# Price Study — SendCutSend, pulled live 2026-08-25

Same part throughout: `bracket_flat_reach130.dxf`, 310 × 730.909 mm, qty 1, cut only unless noted.
Prices are what their instant quote returned, not estimates.

## Thickness / material sweep, sheet cutting only

| Material | Thickness | Price (qty 1) | qty 2 /ea | qty 10 /ea |
|---|---|---|---|---|
| 5052-H32 aluminium | .100" (2.5 mm) | **$59.38** | $47.50 | $30.42 |
| 5052-H32 aluminium | .125" (3.2 mm) | **$61.54** | $45.00 | $34.81 |
| 5052-H32 aluminium | **.187" (4.7 mm)** — as designed | **$131.49** | $86.11 | $61.06 |
| 5052-H32 aluminium | .250" (6.3 mm) | **$127.79** | $91.72 | $76.56 |
| A36/1008 mild steel | .119" (3.0 mm) CRS | **$87.39** | $57.01 | $41.66 |
| A36/1008 mild steel | .135" (3.4 mm) CRS | **$131.68** | $87.27 | $62.99 |

### What the numbers say

**The cliff is between .125" and .187" aluminium — it more than doubles, $61.54 → $131.49.**
Below .125" almost nothing is saved ($59.38 at .100"), so price down there is dominated by cut time
and handling, not material. Above it, .250" is actually *cheaper* than .187" ($127.79), which is
counterintuitive but is what their quote returns — likely stock and nesting, not a typo, since it
reproduced.

**Steel is not the saving.** At equal bending stiffness (E·t³) the match for .187" aluminium is
~3.35 mm of steel, i.e. .135", and that costs $131.68 — dead level with the aluminium it replaces,
while roughly doubling the plate mass. Thinner .119" steel at $87.39 is the only steel worth a
second look, and it gives up stiffness.

## Powder coating

| Option | Price | Delta |
|---|---|---|
| No coating | $151.26 | — |
| **Gloss Black powder coat** | **$220.52** | **+$69.26** |

Includes free deburring. Lead time moves out ~2 days (Sep 1 → Sep 3).

15 colours offered: Gloss / Matte / Wrinkle / Textured Black, Bronze, Textured Gray, Metallic Grey,
Safety Orange, Gloss Red / White / Blue / Green / Grey / Yellow, Matte White.

**Powder coat costs more than the bend and all four countersinks combined.** It is also the single
finishing choice with a mechanical consequence — see the warning below.

## Full ladder, as designed (5052 .187", variant A, qty 1)

| Configuration | Price |
|---|---|
| Sheet cutting | $131.49 |
| + 1 bend @ 90° | $145.70 |
| + 1 countersink | $151.26 |
| + 4 countersinks (projected) | ~$167.94 |
| + Gloss Black powder coat | **~$237.20** |

## Coating and the magnets — CORRECTED 2026-08-25

An earlier version of this document claimed powder coat lands "under the magnets" and costs holding
force, and recommended masking. **That was wrong.** The stack is:

```
fridge steel | magnet rubber face | magnet body 6 mm | screwed to -> plate
```

The magnet's WORKING FACE touches the fridge. The plate sits BEHIND the magnet. Coating the plate
puts material between the plate and the magnet's back, never between the magnet and the steel it
grips. Pull is governed by the face-to-fridge gap, which coating does not change.

**So coat the whole part freely. No masking, no sanding, no penalty.**

What genuinely does open a magnet-to-fridge gap, and is already accounted for:
- the magnet's own rubber coating (it is in the vendor's rated pull, and in our 35% derate)
- paint on the FRIDGE panel (same derate)
- the fridge panel's flatness — a side panel bowed outward means the corner magnets sit off it

One small second-order point in steel's favour: coating between the magnet's steel cup and a
FERROUS plate slightly reduces flux shunting into the plate, if anything a marginal gain.

The only residual concern is coplanarity — four rigid magnets on a plate whose coating varies in
thickness sit at slightly different depths. Powder is uniform to well under 0.05 mm, which is small
against the fridge panel's own flatness. Not worth acting on.

## If cost is the driver

Dropping to **.125" 5052 saves ~$70** and would still be structurally fine on paper — the plate is
hugely overbuilt (neck bending SF 66×, weak axis SF 34× at .187"; roughly 2.25× the stress at .125",
so SF ~29× and ~15×). **But it is not a free swap:**

- Bend radius, minimum flange and **bend deduction all change with thickness**, so the flat pattern
  must be regenerated — `--bend-deduction` from their calculator for .125", and the generator's
  `Material` constants updated.
- Thinner plate is floppier in handling and around the Ø90 vent and windows, which is a feel issue
  rather than a strength one.
- **Countersinks still fit at .125", but only just, and only because our holes are oversized.**
  Their M4 90° countersink has an 8.001 mm major. Depth is `(major − hole)/2`:

  | hole | depth needed | .125" limit (60% × 3.175) | verdict |
  |---|---|---|---|
  | our Ø4.5 | **1.750 mm** | 1.905 mm | **fits**, 0.155 mm to spare |
  | their nominal Ø4.166 | 1.918 mm | 1.905 mm | **exceeds** by 0.013 mm |

  So the very thing that looked sloppy — drawing Ø4.5 instead of their 4.166 minor — is what keeps
  countersinking legal at .125". At .187" both fit comfortably (2.850 mm allowed). Worth confirming
  with them rather than trusting my arithmetic on a 0.155 mm margin.

---

# Thickness Study — strength vs stiffness vs bulk

Generated by `thickness_study.py`; chart in `thickness_study.svg`.

| thickness | mass | screen-edge movement | neck SF | weak-axis SF | M4 c'sink | cut price |
|---|---|---|---|---|---|---|
| .080" (2.03 mm) | 0.83 kg | 1.82 mm | 13x | 6x | **too deep** | — |
| .100" (2.54 mm) | 1.03 kg | 0.93 mm | 20x | 10x | **too deep** | $59.38 |
| .125" (3.17 mm) | 1.29 kg | 0.48 mm | 31x | 15x | fits | $61.54 |
| **.187" (4.75 mm)** | 1.93 kg | **0.14 mm** | 66x | 34x | fits | $131.49 |
| .250" (6.35 mm) | 2.58 kg | 0.06 mm | 110x | 60x | fits | $127.79 |

**Strength is never the limit.** Even at .080" the neck carries 13x and the weak axis 6x. Nothing in
this range comes close to yielding. What changes by a factor of 30 across the range is **stiffness**,
and stiffness is what a hand feels.

"Screen-edge movement" is how far the corner of the display moves under the design load — 5 lbf
pressed at the outer edge, 278 mm off centre. Modelled as a cantilever from the VESA screw out to
the magnet, then amplified geometrically to where the finger actually is. Conservative: the real
plate is supported at four magnets and loaded at four VESA points, so it is stiffer than this
predicts. Treat the numbers as an upper bound and the *ratios* as reliable.

Below .125" the M4 90 deg countersink exceeds the 60%-of-thickness depth limit, so **.100" and
thinner cannot have countersunk VESA holes at all** — screw heads would then stand proud on the
fridge-facing side.

## "Strong but not bulky" — the bulk is not in the plate

| thickness | stack off the fridge | plate's share |
|---|---|---|
| .125" | 62.17 mm | 5.1% |
| .187" | 63.75 mm | 7.5% |
| .250" | 65.35 mm | 9.7% |

Magnet 6.0 + plate + spacer 10.0 + display 43.0. **The display's own 43 mm is two thirds of the
standoff.** Going from .187" to .125" buys back 1.6 mm of a 64 mm stack — invisible — while
tripling the flex. Bulk is not the reason to go thinner; only cost is.

**Recommendation: stay at .187".** It is the thinnest plate that lands inside "feels rigid"
(0.14 mm), it keeps countersinks legal with margin, and the 0.64 kg it adds over .125" is carried by
the hook, not the magnets.

## Powder coat masking — not offered, and not needed

> *"SendCutSend is unable to provide masking or finish specific areas or portions of parts."*

Coating adds **.002"–.005" per side (0.05–0.13 mm)** over the whole part. Per the correction above,
that is harmless here: it never lands between a magnet face and the fridge. Coat the lot.

Also worth knowing: tabs/micro-joints are not removed before coating and stay visible through it,
and tapped holes are not plugged. Neither applies to this part.

---

# Reach x Thickness Matrix

Reach and neck are **independent levers that both add to the same flat length**:

```
flat_length = body(300) + (neck - BD/2) + (reach - BD/2)
```

Neck sets how high the screen hangs. Reach sets how much foot the bracket has on the fridge top.
Neither one trades against the other — they just both cost sheet, at roughly **$0.10 per mm**.

```
Neck fixed at 310 mm  ->  screen centre 1331 mm above the floor  (INSIDE the 1216-1450 mm comfort band)
Sponge pad 6.35 mm; a reach is viable while pad margin >= 1.20x

  thick  reach   flat mm      price    pad   mass  screen move   verdict
------------------------------------------------------------------------------------
  0.125    130     733.0    $61.75   1.59x   1.29       0.48 mm   ok, but flexy
  0.125    180     783.0    $66.75   1.43x   1.37       0.48 mm   ok, but flexy
  0.125    230     833.0    $71.75   1.32x   1.45       0.48 mm   ok, but flexy
  0.125    280     883.0    $76.75   1.25x   1.53       0.48 mm   ok, but flexy
  0.125    326     929.0    $81.35   1.20x   1.61       0.48 mm   ok, but flexy
  0.187    130     730.9   $131.49*  1.59x   1.93       0.14 mm   ok
  0.187    180     780.9   $136.50*  1.43x   2.05       0.14 mm   ok
  0.187    230     830.9   $141.51   1.32x   2.17       0.14 mm   ok
  0.187    280     880.9   $146.52   1.25x   2.30       0.14 mm   ok
  0.187    326     926.9   $151.13   1.20x   2.41       0.14 mm   ok
  0.250    130     728.8   $127.56   1.59x   2.58       0.06 mm   ok
  0.250    180     778.8   $133.00   1.43x   2.75       0.06 mm   ok
  0.250    230     828.8   $138.44   1.32x   2.91       0.06 mm   ok
  0.250    280     878.8   $143.88   1.25x   3.07       0.06 mm   ok
  0.250    326     924.8   $148.88   1.20x   3.22       0.06 mm   ok

*  = actual SendCutSend quote. Unmarked prices are linear interpolation from the
   measured pairs and get less trustworthy the further they extrapolate.

Most reach that still feels rigid and has pad margin: 326 mm at 0.187" — flat 926.9 mm, about $151.13
```

## What this says

**Reach is cheap.** At .187", going from the minimum 130 mm to the pad's limit of 326 mm — an extra
196 mm of foot on the fridge top — costs about **$20**. That is the best value on the whole part.

**The pad, not the price, is the ceiling.** The 1/4" sponge runs out of squash at **326 mm** of
reach, because a longer arm rides further up the crowned top and that stacks with the corner-radius
gap. Step to a **3/8" pad and reach could go past 450 mm** — but then the pad no longer matches the
6 mm magnet height, so the arm magnets would need to be 3/8" tall too, and nobody stocks those.
**Treat 326 mm as the practical maximum.**

**Screen height is not the constraint you might think.** Any neck from **200 to 400 mm** puts the
screen centre inside the 1216-1450 mm band comfortable for 5'1"-6'4":

| neck | screen centre | |
|---|---|---|
| 200 mm | 1441 mm | top of band |
| 260 mm | 1381 mm | variant C |
| 310 mm | 1331 mm | variants A/B, band centre |
| 400 mm | 1241 mm | bottom of band |

So you can pick reach and height almost independently. Only the sum costs money.

## Diminishing returns

Reach resists fore-and-aft rocking by lengthening the lever the arm bears over. Going 130 -> 230 mm
is a large proportional gain. Going 230 -> 326 mm adds much less, while the arm becomes a 326 mm
tongue lying across a 910 mm fridge top — a third of the way over, collecting dust and competing
with whatever you store up there. **230-280 mm is the sweet spot**: most of the structural benefit,
about $10-15 over the minimum, and still an unobtrusive shelf.

## On .250" being cheaper than .187"

Real and reproducible — .250" quotes lower at **qty 1** on both flat lengths tested. But it reverses
at quantity:

| | qty 1 | qty 2 /ea |
|---|---|---|
| .187" variant A | $131.49 | **$86.11** |
| .250" variant A | **$127.79** | $91.72 |
| .187" variant B | $136.50 | **$89.17** |
| .250" variant B | **$133.23** | $95.44 |

A genuinely cheaper material would be cheaper at every quantity. This looks like a setup or nesting
artifact at qty 1. What .250" actually costs you: **+0.65 kg (+35%)** of plate, and 1.6 mm more
exposed edge. What it buys: screen-edge movement drops 0.14 -> 0.06 mm, which is stiffness you
already have at .187".

**Recommendation: stay at .187".** The $3.70 is noise, it evaporates the moment you order two, and
you would be paying for it in weight.

---

# Vent windows, and aluminium vs powder-coated steel

All quoted live 2026-08-25 on the SAME part (310 x 682.958 mm, portrait geometry, neck 262).

## Do the vent windows cost anything?

| | cut length | price, 5052 .187" |
|---|---|---|
| with the four windows | 3565 mm | **$129.46** |
| without them | 2591 mm | **$126.86** |

**$2.60.** Cut length drops 27% and the price barely moves, because the bounding box is unchanged
and material dominates. **Keep the windows** — they are effectively free, and they are the only
direct escape path over the display's rear-box opening.

Note on the internal-CPU-fan point: the openings in the display's rear box are fixed hardware. They
exist whichever fan is fitted, and an internally-cooled Pi still has to push its heat out through
them. The plate does not seal anything — it stands 10 mm off on spacers and is open on all four
edges — but a window directly over the opening is strictly better than solid plate, for $2.60.

## Aluminium vs mild steel

| option | mass | stiffness | screen move | neck SF | non-mag margin | bare | + powder |
|---|---|---|---|---|---|---|---|
| 5052 alu .187" | 1.86 kg | 100% | 0.14 mm | 66x | 2.58x | **$129.46** | $198.72 |
| mild steel .119" | 3.47 kg | 73% | 0.19 mm | 34x | 2.99x | **$86.75** | **$156.01** |
| mild steel .135" | 3.94 kg | 107% | 0.13 mm | 42x | 3.12x | $130.49 | $199.75 |

Stiffness is `E x t^3` relative to the aluminium baseline; screen move is scaled from the measured
0.14 mm. "Non-mag margin" is the arm hold-down over lift demand in the fallback case where the side
panel turns out not to be magnetic — the one place extra mass genuinely helps.

### Heavier IS better here

Confirmed rather than assumed. The hook carries all vertical load, so mass costs nothing
structurally, and it *buys* margin in the non-magnetic fallback: 2.58x -> 3.12x purely from weight.
The only real costs of mass are a two-person install (already true) and a trivial increase in
bearing load at the fridge's top corner.

### But steel changes the finish decision

Bare CRS will surface-rust in a kitchen. Steel effectively **requires** the powder coat, so the
honest comparison is steel+powder against aluminium's chosen finish:

- **Powder coating anyway?** Steel wins. `.119" steel + powder = $156` beats `alu + powder = $199`
  by $43. Or `.135" steel + powder = $200`, same price as aluminium but stiffer and heavier.
- **Happy with bare metal?** Aluminium wins. `$129` bare, and it will not corrode.

### One unverified caveat with steel

The pot magnets would be screwed to a **ferrous** backing plate. Pot magnets carry their own steel
cup which closes the magnetic circuit behind the magnet, so a steel plate behind them should make
little difference — but this is reasoning, not measurement. If going steel, test one magnet against
a steel offcut before committing.

---

# Live re-quote, 2026-08-25 — CURRENT geometry, both reach variants

Everything above this line was quoted against the **old** geometry: before the strap slots, before
the extra magnet rows, and at the old 310 mm neck. Those numbers are superseded. Re-quoted live at
app.sendcutsend.com against `variants/bracket_flat_reach130.dxf` and `..._reach180.dxf` as they
stand today (8 body magnets + 4 top-lip, 10 strap slots, 4 vent windows, 4 VESA patterns).

**A36/1008 mild steel, .119" (3.0 mm) CRS, qty 1, no finishing:**

| variant | blank | cut only | + one 90 deg bend | bend costs |
|---|---|---|---|---|
| reach130 (short) | 310 x 687.0 | **$96.70** | **$108.47** | $11.77 |
| reach180 (long) | 310 x 737.0 | **$101.04** | **$112.81** | $11.77 |
| difference | +50 mm | +$4.34 | **+$4.34** | — |

Quantity breaks on the short reach (cut only): 2 = $64.48 ea, 10 = $48.60 ea, 50 = $34.10 ea.
Both variants quoted "Arrives as soon as Aug 31".

**The long reach costs $4.34.** That is the entire price argument, and it is small enough that reach
should be chosen on fit — how far the arm can sit inboard past the hinge covers on the measured
fridge — rather than on cost.

The bend is a flat **$11.77** on either, and the app read the dashed bend line correctly both times,
reporting "1 Bend" with no intervention. That confirms the DXF bend-line decision end to end on the
current files.

**Cost of the changes since the last quote:** the short reach went $86.75 -> $96.70, i.e. **+$9.95**
for the 10 strap slots and the extra magnet holes. Worth knowing, not worth undoing.

## Finishing, same session

Matte black powder coating is offered on this material and includes deburring free:

| variant | cut only | + 90 deg bend | + matte black powder | coating adds |
|---|---|---|---|---|
| reach130 (short) | $96.70 | $108.47 | **$174.30** | $65.83 |
| reach180 (long) | $101.04 | $112.81 | **$182.54** | $69.73 |
| difference | +$4.34 | +$4.34 | **+$8.24** | |

Coated quantity breaks, short reach: 2 = $123.26 ea, 10 = $92.55 ea, 50 = $71.37 ea.
Lead time slips from **Aug 31 bare to Sep 3 coated**.

**Deburring is already included in every price above** — it is selected by default under Surface
Options, and powder coating includes it free regardless.

## Countersinking is not available on this material

Verified in their app: the Countersinking panel is greyed out on both variants and its tooltip
reads *"This operation is unavailable in this material."* That is a MATERIAL restriction on
A36/1008 mild steel, not the 60%-of-thickness depth cap this document previously blamed. The
depth math was real (1.80 mm needed against an 1.81 mm limit) but it was never the binding
constraint. The decision — ISO 7380 button heads — is unchanged.

## Removing the vent windows COSTS money — verified 2026-08-25

Quoted live, A36/1008 .119", qty 1, cut only, identical blank:

| | cut length | plate area | cut only |
|---|---|---|---|
| with 4 vent windows | 165.5 in | 1447 cm² | **$96.70** |
| no vent windows | 127.2 in (−23%) | 1595 cm² | **$97.38** |

**Removing them makes the part $0.68 dearer.** 23% less cutting does not pay for the 148 cm² of
steel you now keep — SendCutSend's material component tracks the part's own area, and their cut-time
component is small at this size. The windows are better than free: they are a $0.68 discount plus
116 g less mass.

That settles the question the CLAUDE.md vent invariant (§1.5) raised from the other direction: there
is no cost argument for blanking off the display's rear vents, so the invariant costs nothing to
honour. Keep them.

## What the price is actually made of, and why lightening does not pay

Three live points with known geometry (reach130, reach180, no-windows) solve
`price = a·part_area + b·cut_length + c` exactly:

- **$4.005 per 100 cm² of steel**
- **$0.136 per inch of cut**
- **$16.22 fixed** — setup, handling, minimum

So the $96.70 reach130 is roughly **$58 steel + $23 cutting + $16 fixed**.

That gives a hard break-even for any lightening cutout. A circle of radius R saves `a·πR²` of steel
and adds `b·2πR/2.54` of cutting, so it only pays above:

    R = 2b / (2.54·a) = 26.7 mm   ->   diameter 53 mm

| cutout | steel saved | cut added | net |
|---|---|---|---|
| Ø20 mm | $0.13 | $0.34 | **−$0.21** |
| Ø53 mm | $0.88 | $0.89 | $0.00 |
| Ø100 mm | $3.15 | $1.68 | **+$1.46** |
| Ø150 mm | $7.08 | $2.52 | **+$4.55** |

**A field of small lightening holes loses money.** Only a few large openings pay. Removing a
realistic 25% of the plate as Ø100 mm cutouts saves about **$6.74 — 7%** of the part price, for real
topology work, fresh edge-rule validation and recut risk. And it works against the preference for
this bracket to be heavier rather than lighter.

Caveat: three points, three unknowns, so the fit is exact and unvalidated. It predicts nothing yet.
A fourth quote on a deliberately lightened part would test it.

---

## Thickness ladder — live quotes 2026-08-26, on the AS-BUILT `bracket_flat.dxf`

All A36/1008 mild steel, 310 x 692 mm blank, qty 1. "full" = cut + 1 bend at 90 deg + matte black
powder coat. Quoted directly in app.sendcutsend.com against the real upload, not modelled.

| thickness | | bendable | cut only | full | mass | flex under 5 lbf | $/kg |
|---|---|---|---|---|---|---|---|
| .119" | 3.02 mm | yes | $96.07 | **$177.00** | 3.49 kg | 1.44 mm | $50.78 |
| .187" | 4.75 mm | yes | $107.28 | **$188.21** | 5.48 kg | 0.37 mm | $34.36 |
| .250" | 6.35 mm | yes | $137.55 | **$218.48** | 7.32 kg | 0.16 mm | $29.84 |
| .313" | 7.95 mm | **NO** | $186.43 | — | 9.17 kg | 0.08 mm | — |
| .375" | 9.52 mm | **NO** | $248.52 | — | 10.98 kg | 0.05 mm | — |
| .500" | 12.70 mm | **NO** | $297.58 | — | 14.65 kg | 0.02 mm | — |

### The hard ceiling is BENDING, not price
SendCutSend's app, quoted verbatim today: *"Bending isn't available on your selected material or
thickness. On compatible materials, our thickness range is .030" - .250" (varies per material)."*
At .313" and above the Bending panel greys out and the 3D preview stays flat. **.250" is therefore
the thickest this one-piece hook design can ever be.** Anything thicker would need a different
architecture — two pieces bolted or welded — which reopens the whole load path.

### The price curve is NOT monotonic
.187" HRPO ($107.28) is **cheaper than .135" CRS ($141.53)** despite being 39% thicker, because
hot-rolled is cheaper stock than cold-rolled. Do not assume thicker costs more inside this range.

### Thicker material forces a design change
At .187" and .250" the generator REFUSES to write: the centre arm spare hole sits 3.46 mm / 2.45 mm
from the arm strap slots against a 1x-thickness rule that has grown to 4.75 / 6.35 mm. SendCutSend
independently raised a **Deformation Warning** at .250" ("your bend line die area crosses geometry,
1 bend affected") because the die widens from 0.630" to 1.575". Both pass cleanly with
`--no-spare-holes`. So going thick costs the spare-magnet provision unless the strap slots move.

### Denser materials were NOT quoted
Mild steel is the cheapest metal SendCutSend offers, and the density gain from switching is small
(7.85 -> ~8.0 stainless, 8.5 brass, 8.96 copper) against a large price increase. For "heaviest per
dollar" steel wins on reasoning, but this is REASONED, not quoted — if it matters, quote stainless.

---

## Cross-material sweep — live quotes 2026-08-27, on the CURRENT 310 x 742 file

The part changed (reach 130 -> 180, blank 692 -> 742), so every earlier price in this document is
for a SMALLER part and is not comparable. These are quoted against `bracket_flat.dxf` as built.

| material | thickness | cut only | full (bend + matte black) | mass | plate flex |
|---|---|---|---|---|---|
| A36/1008 mild steel CRS | .119" | $103.16 | **$185.54** | 3.71 kg | 0.064 mm |
| A36/1008 mild steel HRPO | .188" | $112.43 | **$197.25** | 5.84 kg | 0.016 mm |
| A36/1008 mild steel HRPO | .250" | $144.33 | ~$229 (projected) | 7.74 kg | 0.007 mm |
| 5052-H32 aluminium | .187" | $144.87 | not quoted | 1.98 kg | 0.047 mm |
| 5052-H32 aluminium | .250" | $145.60 | not quoted | 2.65 kg | 0.020 mm |
| 304 stainless | .187" | $214.60 | not quoted | 5.92 kg | 0.017 mm |

**Mild steel wins on every axis that matters here.** At equal thickness aluminium costs 29 % more
for a third of the stiffness; stainless costs 91 % more for the same stiffness. Steel is
simultaneously the cheapest and the densest practical option, so price and heft do not trade off.

### The "cheap 1/4 inch" — RETIRED
An earlier version of this study recorded 5052 aluminium **.250" ($127.79) cheaper than .187"
($131.49)** and called it counterintuitive but reproducible. **It does not reproduce at the current
geometry**: .187" is $144.87 and .250" is $145.60 — 73 cents apart, i.e. flat, not inverted. Two
things follow: the anomaly was ALUMINIUM, never steel; and it was geometry-specific, so it should
never have been generalised. Steel .250" is $144.33, comfortably dearer than .188" at $112.43.

**The one non-monotonicity that DOES still hold is steel .188" HRPO ($112.43) undercutting .135"
CRS**, because hot-rolled is cheaper stock than cold-rolled. That is a stock-form effect, not a
thickness effect.

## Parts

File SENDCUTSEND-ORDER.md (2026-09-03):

# SendCutSend Order Package — Fridge-Side Display Mount

> **SUPERSEDED IN PART 2026-09-02.** Magnet holes are now O6.5 for the K&J MM-C-32 (M6 stud), standoff 8 mm, pad 5/16 in, eight body magnets fitted, M4 display spacers 10 mm in the model. Read `bracket_params.json` for the geometry and `prices.py` for money; this file is the O48-era order package and is kept as the record.

> **REBUILT 2026-08-27 for the 0.187 in (.188) build.** Every figure in this document was
> previously on the superseded 0.119 in part — thickness, bend deduction, blank size, neck length,
> magnet spacing, stress margins and prices. It also described magnet screws threading into a
> female boss; the specified magnet (McMaster 3506K67) is a **5/16"-18 MALE STUD** and there are no
> magnet screws at all. Cross-check anything surprising against `bracket_params.json`, which the
> generator writes, rather than against this prose.

**A36/1008 mild steel, 0.187" (4.75 mm), portrait, painted textured black.**
Three variants sharing one body, one bend position and one hole pattern. Figures read from
`variants/bracket_params_*.json`; prices are live quotes from 2026-08-25. Regenerate with
`./build_variants.sh` and re-read this document after any change.

Fridge: **Samsung RS23A500ASR**, counter-depth side-by-side. Display: Waveshare 23.8" or 27" FHD
monitor — the bracket is geometrically identical for either.

## 0. Pick one of three

| | **A** `reach130` | **B** `reach180` | **C** `reach180_neck212` |
|---|---|---|---|
| Arm reach across the fridge top | 130 mm | **180 mm** | **180 mm** |
| Neck (drop) | 257 mm | 257 mm | **212 mm** |
| Flat pattern | 310 x **687.0** | 310 x **737.0** | 310 x **687.0** |
| Screen centre above floor | **1331 mm** | **1331 mm** | **1381 mm** |
| Part mass | **3.45 kg** | 3.68 kg | **3.45 kg** |
| Cut price, qty 1 | **~$87** | ~$92 | **~$87** |

Everything else is identical: body 310 x 300, neck/arm width 190, four corner magnets at
246 x 246 spacing, two arm retention magnets, four vent windows on an 87.5 mm radius, O90 centre
vent, VESA 100 plus MIS-E 200x100 and MIS-F 200x200, five pairs of strap slots, and one
90 deg bend 559.5 mm from the body end.

**How to choose.** The reach difference is about $5, so cost is not the deciding factor:

1. **Measure the fridge's top corner radius.** The 1/4 in pad covers a measured **R_f up to 19 mm**
   in steel (the steel bend radius is tighter than aluminium's, which makes the mismatch worse).
   Above that, step the pad up.
2. Otherwise pick on screen height. **A and B put the screen centre at 1331 mm**, mid-band for
   5'1"-6'4". **C puts it at 1381 mm**, 2 in higher. B buys 50 mm more foot on the fridge top.
3. **Unsure? Take A.** Cheapest, lightest, shortest arm.

## 0b. Why steel, and why 0.187"

Decided 2026-08-25 after quoting the alternatives on the identical part:

| | mass | stiffness | screen move | neck SF | non-mag margin | bare | + powder |
|---|---|---|---|---|---|---|---|
| 5052 alu .187" | 1.86 kg | 100% | 0.14 mm | 66x | 2.58x | $129.46 | $198.72 |
| **mild steel .119"** | **3.47 kg** | 73% | 0.19 mm | 34x | **2.99x** | **$86.75** | $156.01 |
| mild steel .135" | 3.94 kg | 107% | 0.13 mm | 42x | 3.12x | $130.49 | $199.75 |

The part is being **coated either way** — SendCutSend powder or textured black rattle can — so bare
corrosion resistance is not a differentiator and steel's price advantage is real: **about $43
cheaper** on either route.

**Mass is a benefit here, not a cost.** The hook carries all vertical load, so weight is
structurally free, and it buys margin in the fallback where the side panel turns out not to be
magnetic: hold-down over lift demand goes 2.58x -> 2.99x purely from the extra weight.

Steel is not a drop-in swap — its published bend radius is **0.063" (3.175 mm)** against aluminium's
0.250", so the bend deduction, the flat length and the corner-radius budget all change. Everything
below is regenerated for steel.

## 1. Order configuration

| Field | Value |
|---|---|
| File to upload | the ONE variant you chose in §0 — `bracket_flat_reach130.dxf`, `..._reach180.dxf` or `..._reach180_neck257.dxf`. **Never** a preview SVG |
| Material | **A36/1008 mild steel** (cold rolled, CRS — smooth and paint-friendly) |
| Thickness | **0.187" (4.75 mm)** |
| Quantity | 1 (a second identical part is $93.47/ea — cheaper than a second variant) |
| Bending | **1 bend**, added in the browser bending tool after upload |
| Countersinking | **None** — see §3. Use low-head screws instead |
| Deburring | Yes — the plate is handled bare-handed during install |
| Finish | Either SendCutSend Gloss Black powder (+$69.26, includes free deburring) or spray it yourself textured black (~$10, saves $59). **Steel must be coated** — bare CRS surface-rusts in a kitchen. No masking needed anywhere |
| Tapping / hardware insertion | None |

Peak working stress in steel is 519 psi against 36 ksi yield — SF 69x. Both the aluminium and
the steel options are enormously overbuilt; the choice was made on cost, mass and finish, not
on strength.

---

## 2. Bend setup

Place the bend in SendCutSend's browser bending tool after upload. **The DXF deliberately contains
no bend line.**

| Parameter | A — reach130 | B — reach180 |
|---|---|---|
| Number of bends | 1 | 1 |
| Bend angle | 90° | 90° |
| Bend centreline from the arm tip | **127.52 mm (5.021")** | **177.52 mm (6.989")** |
| Bend centreline from the body end | **559.52 mm (22.028")** | 559.52 mm (22.028") |
| Bend direction | Either UP or DOWN — same physical part, mirrored. Confirm in the 3D preview that it forms the hook; the fridge sits in the INSIDE (concave) corner of the L | same |
| Inside bend radius after bend | **3.175 mm (0.063")** — much tighter than aluminium | same |
| Bend length | **190 mm (7.48")** | same |
| Bend deduction used | **8.1915 mm (0.3225")** — SendCutSend's published figure | same |
| Formed legs from the bend apex | arm 130, neck+body 562 mm | arm 180, neck+body 562 mm |

### Bend deduction — RESOLVED, no longer an estimate

SendCutSend publishes a full bending table on their
[bending calculator page](https://sendcutsend.com/bending-calculator/). For A36/1008 mild steel at
0.187":

| K factor | Bend deduction @90° | Effective bend radius @90° | Die width | Min formed flange @90° |
|---|---|---|---|---|
| 0.38 | **0.3225"** | **0.063"** | 0.630" | 0.466" |

Those are vendor figures, not derived, and the generator now uses them directly. The K-factor
formula is retained in the code only for thicknesses they do not publish.

**Note the bend radius.** At 0.063" (3.175 mm) it is a quarter of aluminium's 0.250", which makes the
fridge corner-radius mismatch *worse*: `flat_gap = (R_f − R_b) × 0.293`, so a smaller R_b means a
bigger gap. Pad margin drops from 2.51x (aluminium) to **1.62x**, still covering a measured R_f up
to 19 mm.

### Bend lines in the DXF — RESOLVED by testing against their app, 2026-08-25

The brief said bend lines must not appear in the DXF. **That is wrong for their current flow, and
we confirmed it empirically:** uploading a geometry-only file greys out Bending entirely and their
Design Help panel reports

> **"No bend lines detected."** … *Each bend needs a correctly formatted line marking its center.*

with a format table that says **AutoCAD .dxf → Dashed line (not hidden)**.

**The DXF therefore now carries one dashed `LINE` at the bend centre**, spanning exactly the 190 mm
bend length. With it, Bending becomes selectable and the app reports "1 Bend". The line is a marker,
not a cut path — it does not appear in the extents and does not affect price.

`audit_dxf.py` verifies it specifically: count, y position, x span, and that its linetype is
`DASHED` (a solid line would be read as a cut path and would slice the part in half). Regenerate
with `--no-bend-line` only if their flow changes back.

---

## 3. Screw heads on the fridge-facing face — NOT countersunk

The two screw families point in opposite directions:

- **VESA screws** run fridge-side → plate → spacer → display. Their heads land on the
  **fridge-facing** face, inside the 11.51 mm the magnets hold the plate off the panel.
- **Magnet screws** (4 body + 2 arm) run display-side → plate → into the magnet's male stud.
  Their heads face the **display**, where the raised rear box holds the panel 25 mm clear. Nothing
  to be flush with — plain socket cap plus a washer, which clamps better than a countersink and
  removes no material.

On the aluminium build the VESA holes were countersunk. **On 0.187" mild steel they cannot be**,
and the reason is simpler and harder than the geometry argument that used to sit here.

**SendCutSend does not offer countersinking on A36/1008 mild steel at all.** Verified in their quote
app 2026-08-25: the Countersinking panel is greyed out on both reach variants, and its tooltip reads
*"This operation is unavailable in this material."* It is a MATERIAL restriction, not a
depth-versus-thickness one — changing the hole diameter or the plate thickness will not unlock it,
and neither will anything we do to the DXF.

This supersedes an earlier note in this document that blamed the 60% depth cap. That analysis was
real but was not the binding constraint:

| | depth needed | 60% limit | slack | plate left under the cone |
|---|---|---|---|---|
| M4 90° into a Ø4.4 hole, 4.75 mm plate | 1.80 mm | 1.81 mm | **0.01 mm** | 1.22 mm |

So the depth cap would have made it marginal anyway — 0.01 mm of slack, removing 60% of an
already-thin plate at four points — but the operation was never on the menu. Either way the answer
is the same, and it was already the decision.

**Use low-head screws instead** — they achieve the same thing, which is keeping metal away from the
fridge paint:

| screw | head height | clearance to the fridge inside the 11.51 mm standoff |
|---|---|---|
| M4 socket cap, DIN 912 | 4.0 mm | 4.0 mm |
| M4 low head, DIN 7984 | 2.8 mm | 5.2 mm |
| **M4 button head, ISO 7380** | **2.2 mm** | **5.8 mm** — use this |

The generator still validates the depth rule (`countersink_depth` is an ERROR past the 60% limit),
which stays useful if the build ever moves to a material where the operation IS offered — 5052
aluminium, where it was quoted successfully at $5.56 for one countersink.

**Never countersink the FRIDGE-side face of the magnet holes.** The magnet's back must sit flat on
the plate; a cone there would let it rock on its screw.

## 3b. The display is not a slab — and it drives three decisions

Read off Waveshare's dimension drawing
([23.8inch-FHD-Monitor-details-size.jpg](https://www.waveshare.com/img/devkit/LCD/27inch-FHD-Monitor/23.8inch-FHD-Monitor-details-size.jpg)),
not from the spec table:

| Feature | Value |
|---|---|
| Overall depth | **43.00 mm** — not the 18.00 mm the spec page quotes |
| Flat panel section | 18.00 mm |
| Raised rear box | **25.00 mm proud**, footprint **260 × 134 mm**, centred |
| VESA 100 × 100 | **CONFIRMED**, and it is on the raised rear box face |
| Active area / bezel | 528.04 × 297.46 mm / 13.60 mm |
| Panel corner radius | R10.00 |
| Rear box side walls | vented (grille visible in the side view) |
| Rear box **face** | carries the Pi 5's fan and GPIO header, offset **87.5 mm** from the VESA centre on one axis |

**1. The bracket lands on the rear box, not the panel.** The 25 mm box already holds the plate clear
of the panel back. That is a bigger air gap than the spacers were ever going to open.

**2. The spacers stay anyway, and for a better reason than the original one.** The stated rationale
was clearing the magnet screw heads — the box does that on its own. But the box *face* carries the
Pi's fan and GPIO, so a plate bolted flat against it would sit directly on the Pi's cooling. The
10 mm spacers keep a plenum over it. **Do not delete them to save 10 mm of depth.**

**3. The CG is much further out than an 18 mm slab implies**, so the vent windows moved.
Volume-weighting the two sections puts the display's centre of mass **29.45 mm out from the box
face**, giving **d = 50.20 mm** from the fridge — not the 29.75 mm a uniform-slab assumption gives.
Peel rises from 1.09 to **1.75 lbf** and neck bending to 426 psi (SF 66×). Still negligible, but it
was wrong before and it is right now.

The vent windows are now placed on a **radius of 87.5 mm from the VESA centre** rather than a margin
from the plate edge, and widened to 46 mm across. That radius is the fan opening's distance from the
VESA centre, so **one window lands over the Pi's fan in every 90° rotation** — landscape either way
up, portrait either way round. Margin is 8 mm all round.

> ⚠ The 87.5 mm was scaled against the dimensioned 260 mm box width on both drawings (23.8" reads
> 87.5, 27" reads 87.4), so it is better than a guess — but it is still a raster read. Treat it as
> **±5 mm**. The 8 mm of window margin
> covers that, but photograph the rear box face before ordering (checklist §9) and tell me if the
> fan is somewhere else.

## 3c. Upsizing to the 27" — the same bracket fits

Checked against the 27" dimension drawing
([27inch-FHD-Monitor-details-size.jpg](https://www.waveshare.com/img/devkit/LCD/27inch-FHD-Monitor/27inch-FHD-Monitor-details-size.jpg),
saved in `docs/reference/`). The two panels share everything the bracket touches:

| | 23.8" (SKU 34025) | 27" (SKU 33975 US) |
|---|---|---|
| Outer | 555.23 × 324.65 × **43.00** | 629.62 × 367.40 × **43.00** |
| Panel / rear box depth | 18.00 / 25.00 | **identical** |
| **Rear box footprint** | 260 × 134 | **identical** |
| **VESA** | 100 × 100 on the box | **identical** |
| **Fan offset from VESA centre** | 87.5 mm | **87.4 mm** |
| Active area / bezel | 528.04 × 297.46 / 13.60 | 598.68 × 336.46 / 15.47 |
| Panel corner radius | R10.00 | R6.00 |
| Mass | 3.94 kg | **4.92 kg** |
| Power | 36 W typical, ≥ 3 A | same |

The rear box, VESA pattern, depth profile and fan position are the same on both — they use the same
Pi bay assembly in the same housing. **Generating for either produces a geometrically identical
DXF** (verified by hashing the entity geometry: only ezdxf's GUIDs and timestamp differ). So you can
order the bracket now and upsize later without recutting.

`generate_bracket.py --display 27` restates the load case:

| Quantity | 23.8" | 27" |
|---|---|---|
| Total hanging load | 12.90 lbf | **15.06 lbf** |
| Torsion moment (5 lbf at the screen edge) | 54.6 in·lbf | **62.0 in·lbf** |
| Force per magnet | 2.78 lbf | **3.15 lbf** |
| Magnet SF, optimistic / conservative rating | 4.2× / 2.5× | **3.7× / 2.2×** |
| Peel | 1.75 lbf | 2.18 lbf |
| Neck bending | 426 psi, SF 66× | 532 psi, SF 53× |
| Body weak axis | 831 psi, SF 34× | 942 psi, SF 30× |
| Non-magnetic arm-width margin | 1.52× | **1.47×** |
| Screen band, landscape | 1168–1493 mm | 1147–1514 mm |
| Screen band, portrait | 1053–1608 mm | 1016–1646 mm |
| Plate hidden in portrait, per side | 7.3 mm | **28.7 mm** |

Everything still passes, with the two thinnest margins being the conservative magnet rating (2.2×)
and the non-magnetic arm fallback (1.47×). The 27" actually **hides the plate better** — its portrait
width is 367 mm against the 310 mm body, versus 325 mm on the 23.8".

Two things to re-check if you do upsize: the 27" is 1 kg heavier, so re-do the "press hard at the
outer edge" test in step 10 of assembly; and its portrait bottom edge sits at 1016 mm, 37 mm lower
than the 23.8", which is below the taller user's elbow.

## 4. Hole schedule

Origin at the **lower-left corner of the body** (the end furthest from the bend), X right,
Y toward the bend. **No countersinks** — see §3.

| # | Tag | X (mm) | Y (mm) | Ø | Purpose |
|---|---|---|---|---|---|
| 1 | arm_magnet | 95.0 | 594.8 | 8.5 | arm retention magnet, same SKU — anti-jostle only |
| 2 | arm_magnet | 215.0 | 594.8 | 8.5 | arm retention magnet, same SKU — anti-jostle only |
| 3 | arm_magnet | 95.0 | 702.8 | 8.5 | arm retention magnet, same SKU — anti-jostle only |
| 4 | arm_magnet | 215.0 | 702.8 | 8.5 | arm retention magnet, same SKU — anti-jostle only |
| 5 | magnet | 32.0 | 32.0 | 8.5 | pot magnet 5/16"-18 MALE STUD passes through; jam nut + oversized washer behind |
| 6 | magnet | 278.0 | 32.0 | 8.5 | pot magnet 5/16"-18 MALE STUD passes through; jam nut + oversized washer behind |
| 7 | magnet | 32.0 | 278.0 | 8.5 | pot magnet 5/16"-18 MALE STUD passes through; jam nut + oversized washer behind |
| 8 | magnet | 278.0 | 278.0 | 8.5 | pot magnet 5/16"-18 MALE STUD passes through; jam nut + oversized washer behind |
| 9 | spare_arm_magnet | 95.0 | 648.8 | 8.5 | SPARE arm magnet position — cut, left empty |
| 10 | spare_arm_magnet | 155.0 | 648.8 | 8.5 | SPARE arm magnet position — cut, left empty |
| 11 | spare_arm_magnet | 215.0 | 648.8 | 8.5 | SPARE arm magnet position — cut, left empty |
| 12 | spare_magnet | 155.0 | 32.0 | 8.5 | SPARE mid-side magnet position — cut, left empty |
| 13 | spare_magnet | 32.0 | 155.0 | 8.5 | SPARE mid-side magnet position — cut, left empty |
| 14 | spare_magnet | 278.0 | 155.0 | 8.5 | SPARE mid-side magnet position — cut, left empty |
| 15 | spare_magnet | 155.0 | 278.0 | 8.5 | SPARE mid-side magnet position — cut, left empty |
| 16 | vesa | 105.0 | 105.0 | 4.4 | M4 into the display's VESA 100 pattern, through a spacer |
| 17 | vesa | 205.0 | 105.0 | 4.4 | M4 into the display's VESA 100 pattern, through a spacer |
| 18 | vesa | 105.0 | 205.0 | 4.4 | M4 into the display's VESA 100 pattern, through a spacer |
| 19 | vesa | 205.0 | 205.0 | 4.4 | M4 into the display's VESA 100 pattern, through a spacer |
| 20 | vesa100x200 | 105.0 | 55.0 | 4.4 |  |
| 21 | vesa100x200 | 205.0 | 55.0 | 4.4 |  |
| 22 | vesa100x200 | 105.0 | 255.0 | 4.4 |  |
| 23 | vesa100x200 | 205.0 | 255.0 | 4.4 |  |
| 24 | vesa200x100 | 55.0 | 105.0 | 4.4 | MIS-E 200x100, M4 — spare pattern for a larger display |
| 25 | vesa200x100 | 255.0 | 105.0 | 4.4 | MIS-E 200x100, M4 — spare pattern for a larger display |
| 26 | vesa200x100 | 55.0 | 205.0 | 4.4 | MIS-E 200x100, M4 — spare pattern for a larger display |
| 27 | vesa200x100 | 255.0 | 205.0 | 4.4 | MIS-E 200x100, M4 — spare pattern for a larger display |
| 28 | vesa200x200 | 55.0 | 55.0 | 6.5 | MIS-F 200x200, M6 — spare pattern for a larger display |
| 29 | vesa200x200 | 255.0 | 55.0 | 6.5 | MIS-F 200x200, M6 — spare pattern for a larger display |
| 30 | vesa200x200 | 55.0 | 255.0 | 6.5 | MIS-F 200x200, M6 — spare pattern for a larger display |
| 31 | vesa200x200 | 255.0 | 255.0 | 6.5 | MIS-F 200x200, M6 — spare pattern for a larger display |

**31 holes total.** GENERATED from `bracket_params.json` on 2026-08-27 — the previous table was hand-maintained and had drifted: it listed magnet holes at O4.5 for "M4 SHCS into pot-magnet female thread" at inset 30, when the built part has O8.5 clearance holes at inset 32 for a MALE STUD, with the nut on the display side. Do not edit this table by hand; regenerate it.

Vent windows (rounded rectangles, R5 corners), same origin:

| Tag | Centre X | Centre Y | W × H | Covers the rear-box opening in |
|---|---|---|---|---|
| vent_top | 155.0 | 237.5 | 80 × 46 | portrait, one way round |
| vent_bottom | 155.0 | 62.5 | 80 × 46 | portrait, the other |
| vent_left | 67.5 | 150.0 | 46 × 80 | landscape, one way up |
| vent_right | 242.5 | 150.0 | 46 × 80 | landscape, the other |

**Diameter groups**, which is how SendCutSend's app buckets hole operations:

- **4.400 mm — 8 holes** — VESA 100 + MIS-E 200x100 (M4)
- **4.500 mm — 6 holes** — magnets, 4 body + 2 arm (M4)
- **6.500 mm — 4 holes** — MIS-F 200x200 (M6)
- **90.000 mm — 1 hole** — centre vent

All four windows sit on a radius of 87.5 mm from the VESA centre so one
covers the display's rear-box opening in every 90° rotation. Open area 22.7% of the body.
Outer corners R8; the two reflex corners at the neck/body shoulders R6.

## 4b. Cable routing

Five pairs of **strap slots** run up the centreline, positioned as **offsets from the bend line** so
they track any change to neck length or arm reach:

| offset from bend | y in the flat | region | nearest edge |
|---|---|---|---|
| −220 mm | 339.5 | neck | 30.5 mm |
| −130 mm | 429.5 | neck | 85.0 mm |
| −40 mm | 519.5 | neck | 31.0 mm |
| +45 mm | 604.5 | arm | 36.0 mm |
| +105 mm | 664.5 | arm | 13.5 mm |

Each slot is **4.0 mm x 18.0 mm** with R1.40 ends, and the two slots in a pair are 16.0 mm apart
centre to centre — so the **bridge between them is 12.0 mm**. A hook-and-loop strap drops through
one slot, passes behind the bridge and comes back up the other, then wraps the cable.

**Sized for VELCRO Brand ONE-WRAP, 8 in x 1/2 in** (12.7 mm nominal). The 18.0 mm slot length is
12.7 + 2 x 2.65 mm of clearance, which means it also passes a **5/8 in (15.9 mm)** strap with
2.1 mm to spare — a different strap out of the drawer does not mean a different bracket. The 4.0 mm
slot width takes ONE-WRAP's ~1.9 mm laminate with enough room to thread by fingertip.
`--strap-width` re-derives the slot if you standardise on something else.

Two things moved when the round holes became slots, both caught by the validator rather than by
eye:

- the outermost pair went from **+115 to +105 mm**. An 18 mm slot at +115 finishes 3.5 mm from the
  arm tip, inside the 2x-thickness (6.05 mm) edge rule; +105 restores 13.5 mm.
- slots are `WindowRect`s, not holes, so they are **LWPOLYLINEs in the DXF, not CIRCLEs**. The part
  now carries 4 vent windows + 10 strap slots = 14 closed interior contours. The audit reads the
  expected count from `bracket_params.json`, so this needs no manual bookkeeping.

The run is: out of the display's rear box, up behind the display (hidden), up the exposed neck,
over the bend, and onto the fridge top, where the last two pairs hold it down. From there the lead
crosses the top to the rear edge and drops down the back, out of sight.

Note the geometry: the arm points **inboard across the top**, while the back of the fridge is 90°
from that. So the tie-downs get the cable safely onto the top surface; the last leg across to the
rear edge is loose cable, but it is invisible up there.

The −40 pair's slot ends 31 mm from the bend centreline, comfortably outside the 8.00 mm keep-out (½ the
0.630" die). Omit them all with `--no-cable-ties`.

## 5. Constraint compliance

Verified 2026-08-25 against sendcutsend.com. `generate_bracket.py` refuses to write files
and exits non-zero if any of these fail.

| Constraint | Requirement | Actual | Status |
|---|---|---|---|
| Material offered at thickness | A36/1008 in 0.187" CRS | yes | PASS |
| Flat within instant-pricing sheet | ≤ 762 × 1118 mm | 310 × 687.0 mm | PASS |
| Min formed flange, arm side | ≥ 11.84 mm (0.466") | 127.5 mm | PASS |
| Min formed flange, neck side | ≥ 11.84 mm | 259.5 mm | PASS |
| Feature clearance from bend line | ≥ 8.00 mm (½ of the 0.630" die) | 83.0 mm (arm magnet holes) | PASS |
| Min hole diameter | ≥ 1.51 mm (~50% of thickness) | 4.40 mm smallest | PASS |
| Hole to plate edge | ≥ 6.05 mm (2 × thickness) | 27.8 mm | PASS |
| Countersinking | not offered on A36/1008 mild steel (their app, verified) | n/a — ISO 7380 button heads | PASS |
| Magnet disc within its region | overhang ≤ 0 | 8.50 mm inboard | PASS |
| Magnet spacing (load-bearing) | ≥ 240 mm | 250 mm horizontal, 240 vertical | PASS |
| Arm pad covers the corner gap | ≥ 1.2× the budget | 3.32× | PASS |
| Bottom pad vs magnet standoff | 0 to +1.0 mm proud | +0.35 mm | PASS |
| Rear-box opening covered | a window covers it in all 4 rotations | 8.00 mm margin each | PASS |
| Body open area (vents) | ≥ 15% | 22.7% | PASS |
| Corner fillets fit their edges | tangent ≤ ½ each adjacent edge | all fit | PASS |
| DXF: single layer / units / contours | layer 0, $INSUNITS 4, zero open contours | 5 LWPOLYLINE + 19 CIRCLE + 1 dashed bend LINE | PASS |

`audit_dxf.py` runs 15 acceptance checks per variant; all three currently report 0 failures.

### Load-path numbers — steel .119", portrait, 23.8 in display

| Quantity | Value | Note |
|---|---|---|
| Display weight | 8.69 lbf (3.94 kg) | |
| Bracket weight | 7.61 lbf (3.45 kg) | steel, and the mass is a benefit here |
| Total hanging load | **16.29 lbf** | carried entirely by bearing at the fridge top corner |
| Touch press assumed | 5 lbf at 162 mm | portrait halves this arm vs landscape |
| Force per magnet | **1.62 lbf** | over the 250 mm magnet span |
| Magnet safety factor | **7.2×** optimistic, **4.3×** on the conservative 19.8 lbf rating | |
| Peel | 1.77 lbf | d = 48.5 mm, H = 270 mm |
| Neck bending | 1066 psi, **SF 34×** | vs 36 ksi yield |
| Body weak axis | 519 psi, **SF 30×** | conservative strip width. No ribs required |
| Screen centre | **1331 mm** above the floor | portrait: screen spans 1053–1609 mm |
| Arm pad budget | 3.92 mm | covers a measured R_f up to 19 mm |
| Cut length | 3573 mm | |

## 6. Bill of materials — with sources

Prices not quoted; they move. Links are to specific products that match the spec, not endorsements
— check dimensions on the listing before ordering.

### Bracket
| Item | Spec | Qty | Source |
|---|---|---|---|
| Bracket plate | **A36/1008 mild steel 0.187" CRS**, per DXF, 1 bend, no countersinks | 1 | [SendCutSend](https://sendcutsend.com/materials/mild-steel/) |

### Magnets — **one part number for all six**
| Item | Spec | Qty | Source |
|---|---|---|---|
| **Bare Ni-plated neodymium pot magnet** | **Ø36 × 8 mm, M6 FEMALE thread, N38, 71.7 lbf rated** — K&J MM-H-36 | **6** (4 body + 2 arm) | [K&J MM-H-36](https://www.kjmagnetics.com/mm-h-36-metric-internal-thread-mounting-magnet) | [CMS Magnetics, Ø43 × 6 mm M4 female, Amazon](https://www.amazon.com/CMS-MAGNETICS-Durability-Combustible-Environment/dp/B0DD1W4M86) · [AMF Magnets US](https://amfmagnets.com/products/female-thread-neodymium-pot-diameter-43mm-x-6mm-with-rubber-case) · [totalElement](https://totalelement.com/collections/neodymium-threaded-pot-magnets) |

**BARE, not rubber-coated — decided 2026-08-25.** The moulded rubber jacket is ~0.76 mm thick, and
pot-magnet pull falls off steeply with gap. A bare Ø36 magnet rates **71.7 lbf** against the
rubber-coated Ø43's **19.8 lbf** — 3.6× more holding force from the *smaller* magnet. Scratch
protection comes instead from a strip of **electrical tape or thin PTFE film on the fridge** where
each magnet lands: 0.18 mm against the rubber's 0.76 mm, a quarter of the gap.

Consequence for the yank case (a 20 lbf pull at the screen bottom): margin goes **0.83× → 3.00×**
on four magnets. That was the thinnest margin in the design and is now comfortable.

Bare nickel drops μ from ~0.7 to ~0.2, which does not matter here: the hook carries every bit of
the vertical load and the magnets work in tension, not shear.

> **CORRECTED 2026-08-25 — they are not the same magnet.** I previously wrote that vendors
> "disagree badly" about one part. They do not; these are two different products:
>
> | | grade | thread | rated pull |
> |---|---|---|---|
> | AMF / CMS Ø43 × 6 | **N35** | **M4 female** | 9 kg = **19.8 lbf** |
> | totalElement Ø43 × 6.1 | **N52** | **M6 × 15 male stud** | **33.5 lbf** (7 lbf shear) |
>
> The brief's "33.5 lb vertical, 7 lb horizontal" figure came from the N52 male-stud part. The
> female-thread part this BOM specifies is the N35, and **19.8 lbf is its real rating**. Every
> margin quoted against 33.5 lbf assumed the N52.
>
> Buy 8 of whichever you choose and keep spares; you will drop one.

### Fasteners
| Item | Spec | Qty | Source |
|---|---|---|---|
| Magnet screw | **M4 × 10 mm socket head cap**, A2 stainless — 6.98 mm into the magnet's 9 mm thread | 6 | any A2 M4 SHCS assortment |
| Magnet washer | M4 flat, stainless | 6 | " |
| **VESA screw** | **M4 × 20 mm BUTTON HEAD, ISO 7380**, A2 stainless — 2.2 mm head clears the fridge by 3.8 mm | 4 | any A2 ISO 7380 button-head M4 assortment |
| M4 spacer / standoff | **M4 female-female, 10 mm**, brass or stainless — **required, see §3b** | 4 | [uxcell M4 × 10 brass hex standoff](https://www.amazon.com/Hexagon-Female-Brass-Standoff-Spacer/dp/B00NQ9KJC6) |
| Thread locker | Removable (blue) | 1 | on the magnet screws only; keep the display screws serviceable |

**Magnet screw length = plate thickness + 6 to 7 mm of engagement**, and must not exceed the
magnet's 9 mm thread depth or it bottoms out and jacks the magnet off the plate. In the 4.75 mm
steel plate, M4 × 10 gives 6.98 mm — ten threads. M4 × 14 would bottom out. Verify the thread depth
on the magnets you actually receive before ordering screws.

VESA screw length is **3.02 (plate) + 10 (spacer) + engagement**, plus the 2.2 mm button head
sitting proud on the fridge side. 20 mm assumes ~7 mm of thread into the rear box's inserts. **Measure the display's VESA insert depth first** —
bottoming out in a thin aluminium enclosure strips it. Buy 16, 20 and 25 mm if in doubt.
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

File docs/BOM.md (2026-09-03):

# Bill of Materials — Fridge-Side Display Mount

> **SUPERSEDED IN PART 2026-09-02.** Items 3, 4, 5, 5b, 5c and 7 describe the O48 3506K67 magnet and its 5/16-18 stack. The build now carries EIGHT K&J MM-C-32 (O32 x 8 mm, M6 stud, $7.64) on M6 thin nylocs and fender washers, dry, with 5/16 in (8 mm) pad. Money has one home: `prices.py`; the quotes are `quotes.svg` and the page. This file is kept as the record of the O48 build.

> **CORRECTION 2026-08-27.** This BOM was drafted assuming the VESA holes are countersunk 90°. They are NOT — countersinking is disabled in the build because SendCutSend does not offer it on mild steel. Countersinking is NOT needed: the magnets hold the plate 11.5 mm off the panel, so a proud screw head on the fridge-facing side has clearance. Any standard M4 head works — socket cap, pan or low head. Confirmed by the owner. Everything else stands.

**Prices are observations, not derived values.** Every price below was read from the linked
vendor page on **2026-08-27** (SendCutSend: live quote in the owner's own session, same date).
Vendor prices and stock change without notice — **re-check every line before ordering.**
Anything marked NOT VERIFIED could not be confirmed against a live product page and must not
be ordered as written.

Quantities are taken from the generated design (`bracket_params.json` + hole schedule from
`generate_bracket.py`): **8 magnet positions fitted** (4 body `magnet` + 4 arm `arm_magnet`),
**7 spare positions** cut but unfitted (4 `spare_magnet` + 3 `spare_arm_magnet`), 4 VESA 100
holes fitted (200×200 M6 provision cut but unused), pad thickness target 11.5 mm biased under.

## Main BOM

| # | Part number | Description | Qty | Unit price | Ext. price | Source | Status |
|---|---|---|---|---|---|---|---|
| 1 | SendCutSend custom (`bracket_flat.dxf`) | Bracket: A36/1008 mild steel **0.187 in (4.75 mm) HRPO**, **310 × 738.8 mm** flat, 1 bend, **no countersinks**, **Textured Black** powder coat | 1 | **$197.07** | **$197.07** | [sendcutsend.com](https://sendcutsend.com) — live quote 2026-08-27 | VERIFIED (live quote, owner's session) |
| 2 | Waveshare 23.8inch FHD Monitor (SKU 34025) | 23.8 in 1920×1080 capacitive touch monitor, optically bonded, VESA 100, incl. 12 V 5 A PSU + screws pack | 1 | $349.99 | $349.99 | [waveshare.com](https://www.waveshare.com/27inch-fhd-monitor.htm) (select "23.8inch") | VERIFIED |
| 3 | [3506K67](https://www.mcmaster.com/3506K67/) | Encased neodymium magnet, N42, zinc-plated steel case, 1 57/64" OD × 29/64" (11.51 mm) thick, **5/16"-18 × 1/2" male stud**, 175 lbf max pull | 8 | $23.92 | $191.36 | McMaster-Carr | VERIFIED ($20.62 ea at 50+; delivers next day) |
| 4 | [98514A035](https://www.mcmaster.com/98514A035/) | **JAM nut (half height)**, black-oxide 18-8 stainless, **5/16"-18 UNC** (imperial — NOT M8). 1/2" across flats × **3/16" (4.76 mm)** high. Half height is what leaves room for the oversized washer | 1 pack of 25 | $3.20 | $3.20 | McMaster-Carr | **VERIFIED 2026-08-27.** Plain 18-8 is [91847A030](https://www.mcmaster.com/91847A030/), $7.25/100 |
| 5 | [90377A164](https://www.mcmaster.com/90377A164/) | **OVERSIZED washer**, black-oxide 18-8, **Ø1.250" OD / Ø0.344" ID, 0.040"–0.060" thick**. Bears on **732 mm²** of plate — 10× a bare nut, at 54 psi | 2 packs of 10 | $8.37 | $16.74 | McMaster-Carr | **IN 2026-08-27.** Same thickness as the Ø0.750" washer, so the extra diameter costs nothing to fit. Standard size is [96765A145](https://www.mcmaster.com/96765A145/) if preferred |
| 5b | [91458A115](https://www.mcmaster.com/91458A115/) | **Threadlocker, Loctite 243**, medium strength, blue. 105 in·lbf breakaway, removable with hand tools, hardens in 5 min / full strength 24 h. 0.34 fl oz | 1 bottle | $18.42 | $18.42 | McMaster-Carr | **VERIFIED 2026-08-27.** This is the locking feature — the jam nut has none of its own |
| 5c | **NOT SOURCED** | **Adhesive primer** for the threadlocker. McMaster's own copy: primer "is recommended when working with aluminum, **stainless steel**, and titanium; **black-oxide finishes**" — this build is *both*, so treat it as required, not optional | 1 | — | — | McMaster-Carr | **OPEN.** Part number not sourced. See the locking note |
| 6 | [91239A180](https://www.mcmaster.com/91239A180/) | VESA screws: M4 × 0.7, **LOW-HEAD** socket cap, 18-8 stainless — pack of 25. NOT flat head: the plate's VESA holes are NOT countersunk (`countersink_vesa = False`; SendCutSend cannot countersink mild steel), so a 90° flat head would sit proud on a plain hole | 1 pack | NOT VERIFIED | — | McMaster-Carr | **NOT VERIFIED — corrected after the BOM was drafted on a wrong countersink premise. Confirm part number and length before ordering.** |
| 7 | [93375K678](https://www.mcmaster.com/93375K678/) | Neoprene foam strip, closed-cell, **7/16" (11.11 mm) thick**, 2" wide × 10 ft, adhesive-backed, 15 lb/ft³, 12 psi to compress 25% (Soft) | 1 | $141.83 | $141.83 | McMaster-Carr | VERIFIED (price from listing table; see foam note) |
| 8 | [189755](https://www.hookandloop.com/brands/velcro/cable-ties/1-2-velcro-brand-one-wrap-black) | VELCRO® Brand ONE-WRAP®, 1/2" wide, black, 25 yd roll ($1.25/yd) — for the 4.0 × 18.0 mm cable slots | 1 | $31.25 | $31.25 | hookandloop.com | VERIFIED |
| 9 | M4 spacers, ~10 mm, aluminum, unthreaded | Stand display VESA face off the plate; clear the magnet nut stack and keep the rear-vent air channel open | 4 | — | — | [McMaster aluminum unthreaded spacers](https://www.mcmaster.com/products/spacers/material~aluminum/) | **NOT VERIFIED — length depends on measured nut-stack height; pick the part after measuring** |
| 10 | [GST90A12-P1M](https://www.digikey.com/en/products/detail/mean-well-usa-inc/GST90A12-P1M/7703717) | PSU upgrade: Mean Well 12 V / 6.67 A / 80 W desktop brick, barrel 5.5 mm OD × 2.5 mm ID, Level VI (bundled brick is 60 W vs 63 W budget) | 1 | $29.50 | $29.50 | Digi-Key (2,610 in stock) | VERIFIED — **confirm display jack size/polarity first** |
| 11 | [212099-01](https://www.digikey.com/en/products/detail/qualtek/212099-01/5639883) | IEC cord for item 10 (sold without one): NEMA 5-15P → C13, 6 ft, black, SVT 18 AWG | 1 | $7.52 | $7.52 | Digi-Key (3,107 in stock) | VERIFIED |
| 12 | 3506K67 (same SKU as item 3) | Optional: populate the 7 spare magnet positions | 7 | $23.92 | $167.44 | McMaster-Carr | VERIFIED (same page as item 3) |

## Stud length — this changed when the plate went to .188 in

The magnet's stud is a fixed **12.70 mm (1/2 in)**. Every millimetre of plate comes straight off
the thread left for the nut. At the settled **4.75 mm** plate:

**`fastener_matrix.svg` carries all 39 permutations** — 11 nut constructions × 3 washer options ×
with/without threadlocker — each with its arithmetic spelled out. `stack_detail.svg` draws the 17
distinct stack shapes that fit or are marginal. The summary below is the short version. All
combinations are checked against
section in `stack_detail.svg`. Checked against the **thickest** washer McMaster might ship
(0.069 in), because they sell it to a range, not a nominal:

| stack | locking | needs | vs stud | |
|---|---|---|---|---|
| **JAM nut + OVERSIZED washer + threadlocker** | **chemical** | **11.04 mm** | **+1.66 mm** | **SPECIFIED — 732 mm² bearing, the most of anything that fits** |
| JAM nut + threadlocker, no washer | chemical | 9.51 mm | +3.19 mm | fits; most margin of all, least bearing |
| THIN nylon-insert locknut, no washer | mechanical | 11.10 mm | +1.60 mm | runner-up; mechanical lock, 70 mm² |
| distorted-thread locknut, no washer | mechanical | 11.50 mm | +1.20 mm | fits; not reusable, no black |
| washer + nylon-insert locknut | yes | 15.01 mm | −2.31 mm | does not fit |
| nylon-insert locknut, no washer | yes | 13.48 mm | −0.78 mm | does not fit |
| washer + distorted-thread locknut | yes | 13.25 mm | −0.55 mm | does not fit |
| washer + standard hex nut | — | 13.25 mm | −0.55 mm | does not fit |
| washer + THIN nylon-insert locknut | yes | 12.62 mm | +0.08 mm | inside the tolerance stack |
| standard hex nut, no washer | — | 11.50 mm | +1.20 mm | fits, but does not lock |
| distorted-thread locknut, no washer | yes | 11.50 mm | +1.20 mm | fits; runner-up |
| **THIN nylon-insert locknut, no washer** | **yes** | **11.10 mm** | **+1.60 mm** | **use this** |
| washer + JAM nut | — | 11.03 mm | +1.66 mm | fits; does not lock |
| JAM nut, no washer | — | 9.51 mm | +3.19 mm | fits; does not lock |

At the earlier .119 in plate the nyloc-without-washer case worked, which is why this BOM was
first drafted with nylocs. It no longer does. `stack_detail.svg` regenerates from the same
parameters and re-checks itself if the thickness changes again.

### Why the washer is worth the 1.75 mm

Three parts clamp against this plate and they do not share a footprint (all derived in
`engineering_report()`, reported as `*_bearing_area_mm2`):

| bears on the plate | area | pressure at the magnet's 61.2 lbf |
|---|---|---|
| magnet face (Ø48.02 against Ø8.5 hole) | 1754 mm² | 23 psi |
| **washer (Ø19.05 / Ø8.74)** | **225 mm²** | **176 psi** |
| bare thin nut (12.70 AF against Ø8.5 hole) | 70 mm² | 565 psi |

None of these threatens 36 000 psi mild steel — this joint is preloaded by the magnet's own pull,
not by torque. The washer is cheap insurance against point-loading a hole edge, not a structural
necessity.

### Locking — RESOLVED 2026-08-27

An earlier revision of this BOM said no locking feature fits. That was wrong: it tested exactly
one locknut (the standard-height nylon-insert, 8.73 mm), found it too tall, and generalised from
a single sample. **Two locking constructions fit comfortably:**

- **Thin-profile nylon-insert locknut, 1/4" (6.35 mm)** — +1.60 mm to spare, mechanical.
- **Distorted-thread ("all-metal") locknut, 17/64" (6.75 mm)** — +1.20 mm, and the *same height
  as a plain hex nut*, so it adds locking for nothing. Not reusable, not stocked in black.

**CHOSEN 2026-08-27: the third route — a half-height JAM nut with CHEMICAL locking.** A jam nut
is 1.59 mm shorter than the thinnest locknut, which is almost exactly what a washer costs, and
threadlocker adds no height at all. That buys back the washer *and* takes the oversized one for
free, since thickness is what runs out in this stack, not diameter:

| | bearing on the plate | pressure at 61.2 lbf |
|---|---|---|
| specified: oversized washer | **732 mm²** | **54 psi** |
| standard washer | 225 mm² | 176 psi |
| bare nut (either locknut route) | 70 mm² | 565 psi |

**The cost is that chemical locking is not free.** It has to be cleaned off and reapplied to
service the joint, where a nylon insert does not — and McMaster explicitly recommends primer for
stainless *and* for black-oxide finishes, which this build is both of. The primer is item 5c and
is **not sourced**. If that trade is unwelcome, the runner-up is the thin nylon-insert locknut
with no washer (+1.60 mm, mechanical, 70 mm²), which needs no chemicals at all.

**The washer is the thing that had to go, not the locking** — for two independent reasons:

1. **It does not fit.** With the thin locknut a worst-case washer leaves +0.08 mm, which is
   inside the tolerance stack on a stud length, a plate thickness and a washer thickness added
   together. Note *thickness* is what runs out, not diameter — a larger washer would not help.
2. **It is not needed.** The bare nut bears at 565 psi on the plate, ~64× under mild steel's
   36 000 psi yield. There is no point-loading problem for a washer to solve here. A nut backing
   off under touch-cycling, by contrast, is a real failure mode.

### Finish — BLACK OXIDE, specified (2026-08-27)

Only the **arm** fasteners are visible: the plate's nuts hide in the 10 mm spacer gap behind the
display, and every magnet body faces the fridge. On the arm the magnets sit underneath and the
nuts face **up**, where you look straight down at them against a textured-black arm.

| part | plain 18-8 | **black oxide 18-8 (specified)** | delta per piece |
|---|---|---|---|
| **thin nylon-insert locknut** | 90101A237 — $10.34/50 | **90101A122** — $18.72/50 | +$0.17 |
| standard hex nut (not used) | 91841A030 — $8.28/50 | 97149A150 — $6.60/25 | +$0.10 |
| thin/jam hex nut (not used) | 91847A030 — $7.25/100 | 98514A035 — $3.20/25 | +$0.06 |
| washer (not used) | 92141A030 — $7.53/100 | 96765A145 — $15.95/100 | +$0.08 |
| distorted-thread locknut | 90047A115 — $13.45/50 | **not stocked in black** | — |

At 15 magnet positions the black upcharge is **under $3 for the whole build**. Two caveats:
black oxide on stainless is a cosmetic conversion coating with little corrosion resistance (fine
indoors), and it does nothing for the **magnet cases**, which are zinc-plated steel and stay
silver. On the arm they face down and are not visible; on the plate nothing is.

*Black-oxide part numbers were read from the same McMaster tables on 2026-08-27 but at small
screen size — re-check the digits at order time.*

**The thread is 5/16"-18 UNC — imperial.** It is NOT M8. The two are close enough (7.94 vs
8.00 mm) to cross-thread if the wrong box is opened.

## Subtotals

| | |
|---|---|
| **Fitted now** (items 1–8, spacers excluded pending measurement) | **$752.79** |
| **Optional upgrades** (items 10–12: PSU + cord + 7 spare magnets) | **$204.46** |
| Item 9 (spacers) | unpriced until measured — typically < $10 |

At 15 magnets total the order crosses nothing useful; the 50+ price break on 3506K67 is far away.
Nut, washer, and screw packs each cover the full build several times over.

## Measure before ordering

1. **Display VESA insert depth** (item 6 length). M4 × 10 mm leaves only ~5.25 mm of engagement past the
   4.75 mm plate. The display's insert depth is not published; measure the actual monitor before
   committing. Same McMaster family stocks 8/12/16 mm lengths if 10 mm is wrong. The Waveshare
   "screws pack" contents are also unknown until the box is open.
2. **Magnet stud stack-up** (items 3/4/5) — RESOLVED 2026-08-27, see the stud-length section.
   Plate 4.75 + thin nylon-insert locknut 6.35 = 11.10 mm against a 12.70 mm stud, +1.60 mm to
   spare, with a locking feature and no washer. The stale figures that used to sit here were
   computed on the .119 in plate.
3. **Spacer length** (item 9) = whatever the nut stack actually measures proud of the plate
   (~10 mm expected), so the display's rear box lands on spacers, not on nuts.
4. **Display DC jack** (item 10): assumed 5.5/2.5 mm barrel, center-positive — confirm against the
   bundled brick before buying the Mean Well.
5. **Fridge-side unknowns** (affect pads, not cut geometry, but check before final assembly):
   top corner radius `R_f`, whether the Samsung side panel is magnetic at all, hinge-cover
   clearance. See CLAUDE.md §2.
6. **SendCutSend bend deduction**: replace the generator's estimated BD with their bending
   calculator value before the production order.

## Foam note (item 7)

7/16" (11.11 mm) is the thickest adhesive-backed closed-cell neoprene McMaster stocks that stays
**under** the 11.51 mm magnet face height — it exists only as **strips** (max 2" wide, 10 ft);
their sheet line jumps 3/8" → 1/2", and 1/2" (12.7 mm) would stand proud of the magnets. The
design's 72 mm-wide neck pads must therefore be built up from strip runs (one 2" run + one ~21 mm
rip per pad), and the arm/bottom pads pieced the same way. One 2" × 10 ft roll (0.155 m²) covers
the whole pad plan (~0.115 m²) with margin. Cheaper narrower rolls exist on the same listing
(1" × 10 ft = [93375K677](https://www.mcmaster.com/93375K677/), $76.83) if piecing from 1" runs is
acceptable. Note the stocked foam is rated Soft (12 psi to compress 25%), not the 50–60A "firm"
originally intended — see Decisions.

## Substitutions that would work

- **Locknuts**: it must be a **THIN-PROFILE** 5/16"-18 locknut — a standard-height nylon-insert
  nut is 8.73 mm and does not fit, whatever it is made of. The only other construction that fits
  is the distorted-thread type at 17/64" ([90047A115](https://www.mcmaster.com/90047A115/),
  $13.45/50, plain only). Check the **height** column, not the description.
- **Washers**: the standard Ø0.750" size ([96765A145](https://www.mcmaster.com/96765A145/)) fits
  the same stack, but bears on 225 mm² instead of 732 mm² — it gives up two thirds of the bearing area for no gain, since both are the same thickness. Anything thicker than **0.060"** does not fit.
- **VESA screws**: any standard M4 head — socket cap, pan or low head. The holes are NOT countersunk and do not need to be: the 11.5 mm magnet standoff clears the head. Material is
  non-structural here. Black-oxide is specified for consistency with the magnet fasteners.
- **Foam**: blended Buna-N/neoprene/vinyl strips on the same McMaster listing, or EPDM equivalents,
  as long as closed-cell, adhesive-backed, and ≤ 11.51 mm thick.
- **Strap**: 5/8" ONE-WRAP also passes the 18 mm slots; 3/4" (19.05 mm) does **not**.
- **PSU**: any regulated 12 V ≥ 80 W Level VI brick with the correct barrel; GST120A12-R7B
  (102 W, $42.90 at Digi-Key) if headroom is wanted, but it uses a 4-pin DIN plug — wrong
  connector as shipped.
- **Not substitutable**: the magnets' male-stud style is load-bearing for the flat mounting plane
  (female-thread pots would need a screw head on the display side); the 7/16"-under-11.51 mm foam
  bias; the 240 mm magnet-spacing floor (geometry, not a purchasable).

## DECISIONS NEEDED

1. **Washer under the magnet nuts, or not?** The 1/2" stud is ~0.3 mm too short for full nylon
   engagement with a standard washer in the stack. Options: (a) omit the washer — full collar
   engagement, nut bears directly on plate (**recommended**; the joint is torsion-loaded shear,
   not tension, and the plate face is powder-coated steel); (b) keep the washer and accept partial
   collar engagement; (c) source a thinner washer.
2. **Foam width strategy**: one 2" × 10 ft roll pieced into 72 mm pads ($141.83,
   **recommended** — fewest seams), or two 1" × 10 ft rolls ($153.66 total), given no 72 mm-wide
   stock exists at 7/16".
3. **Accept Soft-rated foam?** Stocked 7/16" neoprene is 12 psi-to-compress (Soft), not the 50–60A
   firm sponge in the brief. **Recommended: accept** — the pad's job is conforming to the corner
   radius, and the hook (not the pad) carries the load; a 50–60A solid rubber pad at
   this thickness is not a stocked item anywhere obvious. If Charles disagrees, the search widens
   to Grainger/Rubber-Cal custom-cut.
4. **Buy the PSU upgrade now or try the bundled 60 W brick first?** 63 W budget vs 60 W brick is
   only over budget when the Pi 5 peaks. **Recommended: order items 10–11 with the rest** — $37
   against a bricked boot-loop debugging session, and next-day availability either way.

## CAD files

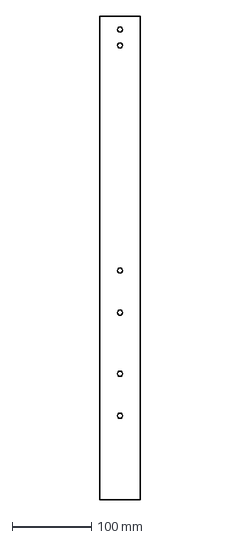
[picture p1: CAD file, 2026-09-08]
angle/dxf/D4_bar.dxf
50.8 x 609.6 mm

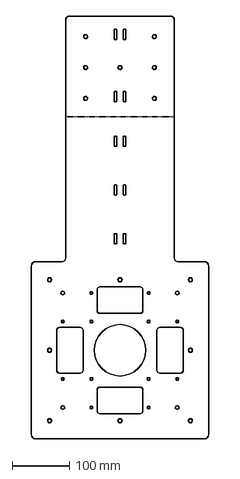
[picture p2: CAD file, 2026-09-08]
bracket_flat.dxf
310.0 x 738.8 mm

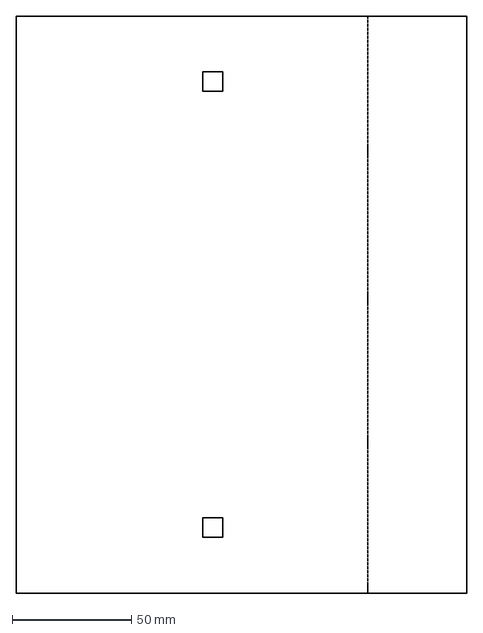
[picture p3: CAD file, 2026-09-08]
strut/dxf/A_clamp_bar.dxf
189.0 x 242.3 mm

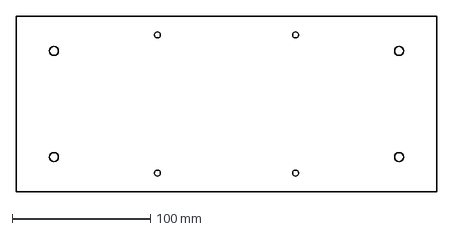
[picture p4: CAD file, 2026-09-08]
angle/dxf/D4_plate.dxf
304.8 x 127.0 mm

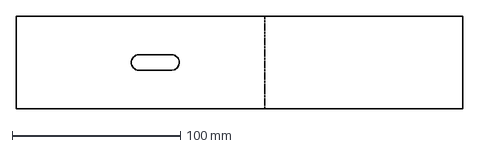
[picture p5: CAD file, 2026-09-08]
strut/dxf/B_foot.dxf
265.0 x 55.0 mm

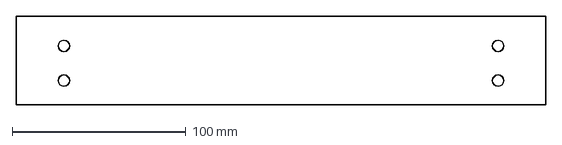
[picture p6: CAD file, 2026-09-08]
angle/dxf/D4_clip_leg.dxf
304.8 x 50.8 mm

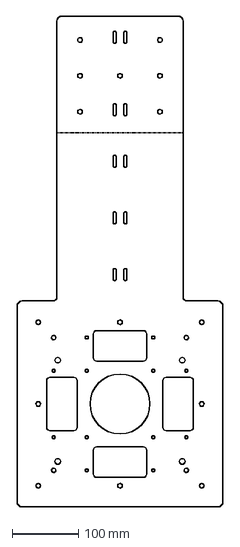
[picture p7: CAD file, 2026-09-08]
strut/dxf/H_hook_plate.dxf
310.0 x 738.8 mm

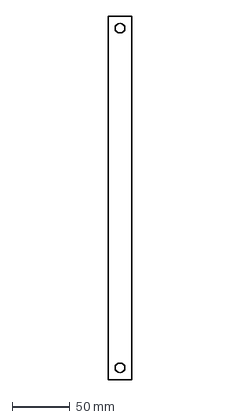
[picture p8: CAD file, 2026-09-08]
strut/dxf/D_backing_strip.dxf
20.0 x 315.9 mm

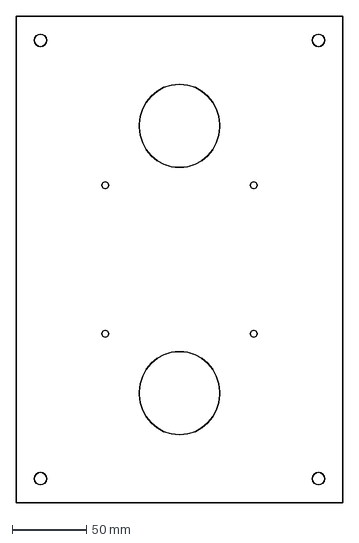
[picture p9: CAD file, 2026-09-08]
strut/dxf/C_plate.dxf
219.9 x 327.9 mm

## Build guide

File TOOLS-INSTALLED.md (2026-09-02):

# Tools installed for this project

| what | why | uninstall |
|---|---|---|
| `.venv` + **ezdxf 1.4.x** | the DXF generator and audit | `rm -rf ~/work/claude/chore-tracker-mount/.venv` |
| `.venv` + **gmsh 4.15 (pip wheel, bundles the binary)**, **scikit-fem 11**, numpy, scipy, meshio | `plate_fea.py`: a Kirchhoff plate finite-element check of the body plate with its real holes, replacing the strip-beam estimate with a plate answer. Installed 2026-09-01 at Charles's request. Homebrew has no CalculiX formula, so this is the pure-pip route. | same `rm -rf .venv`; nothing outside it was touched |

Nothing was installed system-wide and no system configuration was changed.

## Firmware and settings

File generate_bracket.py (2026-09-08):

#!/usr/bin/env python3
"""Parametric flat-pattern generator for the fridge-side display mount bracket.

Formed (post-bend) dimensions are the inputs. The flat pattern is derived by subtracting
the bend deduction, half from each leg. Validation runs before anything is written; if a
check fails, no files are produced and the process exits non-zero.

See CLAUDE.md for the design invariants this implements.
"""

from __future__ import annotations

import argparse
import json
import logging
import math
import sys
from dataclasses import dataclass, field
from pathlib import Path
from typing import Sequence

import ezdxf
from ezdxf.math import bulge_to_arc

from bracket_common import (
    FRIDGE_SIDE,
    FRIDGE_SIDE_EDGE,
    ON_FRIDGE_BAD,
    INSUNITS_MILLIMETERS,
    LOG_LEVELS,
    REQUIRED_LAYER,
    configure_logging,
)

LOG = logging.getLogger("generate")

MM_PER_INCH = 25.4
LBF_PER_KG = 2.2046226218  # weight in lb of one kg under standard gravity
GRAVITY_SF = 1.0

# ---------------------------------------------------------------------------
# Material / vendor constants (verified against sendcutsend.com — see CLAUDE.md §3)
# ---------------------------------------------------------------------------


# SendCutSend's published bending table for 5052-H32, read from their bending-calculator page
# on 2026-08-25. Columns: K factor, bend deduction @90 deg, effective bend radius @90 deg, die
# width, minimum FORMED flange length @90 deg — all inches. These are vendor figures, not
# estimates, and they supersede the K-factor formula that used to derive the bend deduction here.
# Note .187" and .250" share the same 0.250" effective bend radius: going thicker buys no
# corner-radius tolerance.
BEND_SPECS = {}
BEND_SPECS_5052 = {
    0.040: (0.45, 0.062, 0.024, 0.472, 0.286),
    0.063: (0.42, 0.096, 0.035, 0.472, 0.303),
    0.080: (0.48, 0.116, 0.038, 0.472, 0.313),
    0.090: (0.37, 0.142, 0.032, 0.472, 0.326),
    0.100: (0.40, 0.191, 0.125, 0.630, 0.463),
    0.125: (0.44, 0.216, 0.125, 0.630, 0.476),
    0.187: (0.43, 0.356, 0.250, 0.984, 0.798),
    0.250: (0.42, 0.442, 0.250, 1.575, 1.371),
}

# A36/1008 mild steel, same table, same source. Note how much TIGHTER the effective bend radius is
# than aluminium at comparable thickness (.063" vs .250"), which makes the corner-radius mismatch
# WORSE, not better: flat_gap grows as (R_f - R_b).
BEND_SPECS_MILD_STEEL = {
    0.030: (0.38, 0.0610, 0.045, 0.472, 0.286),
    0.048: (0.38, 0.0860, 0.045, 0.472, 0.298),
    0.059: (0.40, 0.1080, 0.063, 0.472, 0.309),
    0.074: (0.40, 0.1290, 0.063, 0.472, 0.320),
    0.104: (0.34, 0.1815, 0.063, 0.630, 0.459),
    0.119: (0.38, 0.1955, 0.063, 0.630, 0.466),
    0.135: (0.32, 0.2440, 0.100, 0.984, 0.742),
    0.187: (0.36, 0.3225, 0.125, 0.984, 0.781),
    0.250: (0.36, 0.4215, 0.150, 1.575, 1.361),
}

# name -> (spec table, yield psi, density g/cc, human label)
MATERIALS = {
    "5052": (BEND_SPECS_5052, 28_000.0, 2.68, "5052-H32 aluminium"),
    "mild-steel": (BEND_SPECS_MILD_STEEL, 36_000.0, 7.85, "A36/1008 mild steel"),
}


@dataclass(frozen=True)
class Material:
    """5052-H32 as SendCutSend publishes it. All lengths mm unless named otherwise."""

    family: str = "mild-steel"
    # 0.187 in (SendCutSend list it as .188), HRPO. SETTLED 2026-08-27.
    # Chosen for HEFT and margin, not for stiffness-you-can-feel: plate flex under a touch is
    # 0.016 mm here against 0.064 mm at 0.119 in, and neither is perceptible. What it buys is
    # 5.84 kg instead of 3.71 kg and the best $/kg and stiffness-per-dollar in the whole
    # material sweep — hot-rolled is cheaper stock than cold-rolled, which is why .188 HRPO
    # undercuts .135 CRS despite being thicker. +$11.21 over the 0.119 build.
    thickness_in: float = 0.187

    @property
    def name(self) -> str:
        return MATERIALS[self.family][3]

    @property
    def yield_psi(self) -> float:
        return MATERIALS[self.family][1]

    @property
    def density_g_cc(self) -> float:
        return MATERIALS[self.family][2]

    @property
    def _spec(self) -> tuple[float, float, float, float, float]:
        return MATERIALS[self.family][0][self.thickness_in]

    @property
    def k_factor(self) -> float:
        return self._spec[0]

    @property
    def published_bend_deduction_in(self) -> float:
        return self._spec[1]

    @property
    def published_bend_deduction(self) -> float:
        return self._spec[1] * MM_PER_INCH

    @property
    def bend_radius_in(self) -> float:
        return self._spec[2]

    @property
    def die_width_in(self) -> float:
        return self._spec[3]

    @property
    def min_flange_in(self) -> float:
        return self._spec[4]

    die_min_in: float = 0.472
    sheet_max_in: tuple[float, float] = (30.0, 44.0)

    @property
    def thickness(self) -> float:
        return self.thickness_in * MM_PER_INCH

    @property
    def bend_radius(self) -> float:
        return self.bend_radius_in * MM_PER_INCH

    @property
    def min_flange(self) -> float:
        return self.min_flange_in * MM_PER_INCH

    @property
    def die_width(self) -> float:
        return self.die_width_in * MM_PER_INCH

    @property
    def bend_clearance(self) -> float:
        """Cut features must clear the bend centerline by half the die used for THIS thickness.

        Previously this assumed the widest die they own (1.575"), which was needlessly
        conservative: their published table gives the actual die per thickness.
        """
        return self.die_width / 2.0

    @property
    def min_hole_dia(self) -> float:
        """Laser pierce floor: roughly 50% of material thickness."""
        return 0.5 * self.thickness

    @property
    def min_edge_distance(self) -> float:
        """Hole/feature to edge. SendCutSend publishes 2x thickness; the brief's floor is 1x."""
        return 2.0 * self.thickness

    @property
    def sheet_max(self) -> tuple[float, float]:
        return (self.sheet_max_in[0] * MM_PER_INCH, self.sheet_max_in[1] * MM_PER_INCH)


@dataclass(frozen=True)
class Display:
    """Waveshare 23.8in FHD Monitor, SKU 34025.

    NOT a uniform slab. Read off Waveshare's dimension drawing
    (waveshare.com/img/devkit/LCD/27inch-FHD-Monitor/23.8inch-FHD-Monitor-details-size.jpg):
    a flat 18 mm panel with a 25 mm raised rear box, 43 mm overall. The VESA 100 pattern is on
    that raised box, so the bracket lands on the box face and stands 25 mm clear of the panel.
    """

    width: float = 555.23
    height: float = 324.65
    panel_depth: float = 18.00  # flat panel section
    rear_box_depth: float = 25.00  # how far the raised rear housing stands proud of the panel back
    rear_box_w: float = 260.00
    rear_box_h: float = 134.00
    active_w: float = 528.04
    active_h: float = 297.46
    bezel: float = 13.60
    corner_radius: float = 10.00
    mass_kg: float = 3.94
    vesa: float = 100.0  # CONFIRMED on the dimension drawing, on the rear box face
    watts: float = 36.0
    # Pi 5 fan / GPIO opening in the REAR BOX FACE, measured off the drawing at roughly 82 mm from
    # the VESA centre along one axis. Scaled from a raster drawing, so call it +/- 5 mm and confirm
    # against the physical unit. This is the thing the plate must not blank off.
    # Measured against the dimensioned 260 mm box width on each drawing: 99 px / 1.131 px-per-mm
    # on the 23.8in and 100.5 px / 1.150 on the 27in, i.e. 87.5 and 87.4 mm. The two agree because
    # both sizes use the same Pi bay assembly in the same 260 x 134 box. Still a raster read, so
    # +/- 5 mm.
    rear_face_feature_radius: float = 87.5
    rear_face_feature_dia: float = 30.0

    @property
    def depth(self) -> float:
        """Overall depth, panel plus raised rear box."""
        return self.panel_depth + self.rear_box_depth

    @property
    def weight_lbf(self) -> float:
        return self.mass_kg * LBF_PER_KG

    def centroid_from_box_face(self) -> float:
        """Depth of the display's centre of mass, measured out from the rear box face.

        Volume-weighted across the two sections rather than assumed at mid-depth: the panel is the
        bulk of the volume but sits furthest out, and getting this wrong understates the
        overturning moment. Volume is a proxy for mass here — the panel is glass, backlight and
        aluminium while the box holds a PCB and a fan, so this is an estimate, not a measurement.
        """
        box_volume = self.rear_box_w * self.rear_box_h * self.rear_box_depth
        panel_volume = self.width * self.height * self.panel_depth
        box_centroid = self.rear_box_depth / 2.0
        panel_centroid = self.rear_box_depth + self.panel_depth / 2.0
        return (box_volume * box_centroid + panel_volume * panel_centroid) / (box_volume + panel_volume)


# Both Waveshare panels share the rear box, the VESA pattern, the depth profile and the Pi bay, so
# one bracket serves either. Only mass and the torsion arm change.
DISPLAYS: dict[str, Display] = {
    "23.8": Display(),
    "27": Display(
        width=629.62,
        height=367.40,
        active_w=598.68,
        active_h=336.46,
        bezel=15.47,
        corner_radius=6.00,
        mass_kg=4.92,
    ),
}

MATERIAL = Material()


def set_material(family: str, thickness_in: float) -> None:
    """Select material and thickness. Rebinds the module-level MATERIAL."""
    global MATERIAL
    if thickness_in not in MATERIALS[family][0]:
        raise SystemExit(f"{family} is not bendable at {thickness_in}\" — SendCutSend publishes "
                         f"bend specs only for {sorted(MATERIALS[family][0])}")
    MATERIAL = Material(family=family, thickness_in=thickness_in)
    LOG.info("Material: %s at %.3f in (%.3f mm) — K %.2f, bend deduction %.4f in, "
             "effective bend radius %.3f in (%.2f mm), die %.3f in, min formed flange %.3f in",
             MATERIAL.name, MATERIAL.thickness_in, MATERIAL.thickness, MATERIAL.k_factor,
             MATERIAL.published_bend_deduction_in, MATERIAL.bend_radius_in, MATERIAL.bend_radius,
             MATERIAL.die_width_in, MATERIAL.min_flange_in)
DISPLAY = DISPLAYS["23.8"]


def set_display(name: str) -> None:
    """Select the panel the bracket is being generated for. Rebinds the module-level DISPLAY."""
    global DISPLAY
    DISPLAY = DISPLAYS[name]
    LOG.info(
        "Display: Waveshare %sin — %.2f x %.2f mm, %.2f kg, rear box %.0f x %.0f x %.0f, VESA %.0f",
        name, DISPLAY.width, DISPLAY.height, DISPLAY.mass_kg, DISPLAY.rear_box_w,
        DISPLAY.rear_box_h, DISPLAY.rear_box_depth, DISPLAY.vesa,
    )


# ---------------------------------------------------------------------------
# Parameters
# ---------------------------------------------------------------------------


@dataclass
class BracketParams:
    """Formed (post-bend) geometry plus load-case inputs. Every length in mm."""

    # PORTRAIT is now the default, decided 2026-08-25. Two independent reasons:
    #  1. Dimensional — the fridge is counter-depth, so the side panel is only 610 mm front to
    #     back and the door sweeps the front ~64 mm of it. A 555 mm landscape display does not
    #     fit the 546 mm usable window; a 325 mm portrait one fits with 221 mm to spare.
    #  2. Mechanical — the brief already noted it: the touch-torsion arm drops from 278 mm to
    #     162 mm, roughly halving the load the magnets have to hold.
    orientation: str = "portrait"
    # 310 wide (not the brief's 300) buys 250 mm of horizontal magnet spacing against the
    # 240 mm floor. Torsion is about the VERTICAL axis, so only the horizontal span carries it.
    # The ceiling is portrait: the display is only 324.65 mm wide that way, so a body wider than
    # about 310 mm stops hiding behind it.
    body_w: float = 310.0
    # 310, matching the width. The width was grown 300 -> 310 to clear the 240 mm torsion
    # floor; the height was left at the brief's 300 and never revisited, which made Y spacing
    # permanently 10 mm tighter than X and is what blocked every larger magnet. Square fixes it.
    # The display is 324.65 mm wide in portrait, so a 310 mm plate is still fully hidden.
    body_h: float = 310.0
    # 190 mm (not the brief's 130) roughly halves the couple force at the bend under a touch
    # press, which is what holds the arm down if the side panel turns out to be non-magnetic.
    # Width runs front-to-back, where the fridge top is straight, so it costs no sheet: the
    # bounding box is already set by the body.
    neck_w: float = 190.0
    # bend apex -> body top edge. Puts the screen centre at 1331 mm on a 1791 mm fridge, the
    # middle of the band comfortable for 5'1"-6'4". MEASURE the fridge and re-derive.
    neck_len: float = 257.0  # puts the screen centre at 1331 mm on the 1743 mm Samsung case
    # ---- Samsung RS23A500ASR, 23 cu ft COUNTER-DEPTH side-by-side --------------------
    # From Samsung's published spec sheet (us-specsheet-rs23a500asr-aa-551113934.pdf):
    #   with hinges, handles and doors : 35 7/8" x 70 1/16" x 28 5/8"
    #   WITHOUT hinges and door        : 35 7/8" x 68 5/8"  x 24"
    # The arm rests on the CASE, so 68 5/8" (1743.1 mm) is the height that matters, not the
    # 70 1/16" hinge figure. MEASURE yours — installed height varies with the levelling feet.
    fridge_height: float = 68.625 * MM_PER_INCH  # 1743.1 mm, top of case
    # Hinge covers stand this far above the case top (70 1/16" - 68 5/8"). The arm lands behind them.
    hinge_cover_proud: float = (70.0625 - 68.625) * MM_PER_INCH  # 36.5 mm

    # Hinge cover footprint, MEASURED from the 2026-08-27 photo — which is a view of the LEFT
    # SIDE PANEL, the face the display hangs on. The ruler therefore runs FRONT-TO-BACK along the
    # top of that panel, not across the width. Datum is the REAR edge of the top.
    #
    # Sanity check that settles the reading: the photo shows the fridge edge at ruler ~27.5 in.
    # Case depth 24 in + doors projecting 4.6 in = 28.6 in. A FRONT view would have had to read
    # 35.9 in. The side reading needs no fudge; the front reading did.
    #
    # CONSEQUENCE: the cover constrains ARM WIDTH (which runs front-to-back), not arm reach.
    # This is the "clear window on the fridge top, front to back" that the pre-order checklist
    # calls the likeliest recut risk. It is now measured, and it passes.
    hinge_cover_from_rear: float = 16.0 * MM_PER_INCH    # 406 mm — cover's rear-most edge
    # How far the cover reaches INBOARD from the mounting-side edge. NOT resolvable from the
    # 2026-08-27 photo, which is a side elevation and shows no inboard extent. 104 mm is a
    # placeholder sized off the visible moulding; it does not affect the clearance result,
    # because the arm starts at the same edge and so overlaps the cover inboard-wise regardless.
    # ONLY the front-to-back position decides whether they touch.
    hinge_cover_inboard: float = 104.0   # ASSUMED — measure if it ever matters

    # Where the plate sits FRONT-TO-BACK on the side panel, measured from the REAR edge.
    # This decides whether the arm meets the hinge cover, and it had no home until 2026-08-27 —
    # the clearance was being quoted as if the arm sat hard against the rear edge, which was
    # never stated anywhere. DERIVED, not chosen: centre the plate on the panel.
    #
    # A neat consequence, and the reason this placement is the right default: the panel is 24 in
    # deep, so thirds are 8 in. Centring the plate ALSO centres the 190 mm (7.48 in) arm in the
    # middle third, and the hinge cover begins at 406 mm against a 406.4 mm two-thirds line — it
    # owns the front third almost exactly. Rear third free, middle third arm, front third hinge.
    # The margin is only 6.6 mm each side, though: that is 203.2 - 190 halved, not an allowance.
    plate_from_rear_override: float = 0.0

    # --- foam behind the plate ------------------------------------------------------------
    # The plate stands off the panel by the magnet height, so along the neck there is an open
    # gap. Fill it, or the mount drums against the fridge and the space reads as unfinished.
    # TWO strips, not one slab: the strap slots run down the centreline and a hook-and-loop band
    # has to pass through them and lie behind the plate. A solid pad would block that.
    foam_strips: bool = True

    @property
    def foam_channel_w(self) -> float:
        """Clear centre channel: the strap-slot pair, plus a strap width of room each side."""
        pair_span = self.cable_tie_pair_gap + self.strap_slot_thickness
        return pair_span + 2.0 * self.strap_width

    @property
    def foam_strip_w(self) -> float:
        """Each side strip. Whatever the channel leaves of the neck width."""
        return (self.neck_w - self.foam_channel_w) / 2.0

    @property
    def plate_from_rear(self) -> float:
        """Plate centred on the side panel, front to back."""
        if self.plate_from_rear_override:
            return self.plate_from_rear_override
        return (self.fridge_depth - self.body_h) / 2.0
    # Charles reports the cover LIFTS slightly, so thin material can be slipped under it. Not
    # relied on: the arm clears it by 216 mm, so this is a fallback, not part of the design.
    hinge_cover_lifts: bool = True
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

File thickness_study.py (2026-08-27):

#!/usr/bin/env python3
"""Thickness study for the fridge-side display mount.

Strength is NOT the deciding factor — the plate is enormously overbuilt at every thickness
SendCutSend offers. Stiffness is. What a user actually perceives is how far the screen edge moves
when they press it, and that scales as 1/t^3, so it changes dramatically across the range while the
safety factors stay comfortable throughout.

Renders a table and an annotated chart. Reference-only.
"""

from __future__ import annotations

import argparse
import logging
import math
import sys
from dataclasses import dataclass
from pathlib import Path
from typing import Sequence

from bracket_common import LOG_LEVELS, configure_logging
from generate_bracket import DISPLAY, MATERIAL, MM_PER_INCH, BracketParams

LOG = logging.getLogger("thickness")

E_5052_MPA = 70_300.0  # Young's modulus, N/mm^2
N_PER_LBF = 4.4482216

# Live SendCutSend quotes, same part, qty 1, cutting only. Pulled 2026-08-25.
QUOTED_PRICE_USD = {0.100: 59.38, 0.125: 61.54, 0.187: 131.49, 0.250: 127.79}

# Powder coat adds this per side, so it lands on the magnet pads. Masking is NOT offered.
POWDER_PER_SIDE_IN = (0.002, 0.005)


@dataclass(frozen=True)
class Result:
    thickness_in: float
    thickness_mm: float
    neck_psi: float
    neck_sf: float
    body_psi: float
    body_sf: float
    magnet_deflection_mm: float
    screen_edge_movement_mm: float
    mass_kg: float
    countersink_depth_mm: float
    countersink_limit_mm: float
    price_usd: float | None

    @property
    def countersink_ok(self) -> bool:
        return self.countersink_depth_mm <= self.countersink_limit_mm


def evaluate(thickness_in: float, params: BracketParams) -> Result:
    t = thickness_in * MM_PER_INCH

    # Torsion from a touch press at the outer screen edge, reacted by the magnet pairs.
    torsion_in_lbf = params.press_force_lbf * (params.torsion_arm / MM_PER_INCH)
    force_per_magnet_lbf = torsion_in_lbf / (params.magnet_spacing_x / MM_PER_INCH) / 2.0

    # Plate area scales nothing but mass; openings deducted the same way the generator does.
    area_mm2 = (
        params.body_w * params.body_h
        + params.neck_w * (params.neck_len + params.arm_len)
        - math.pi * (params.center_open_dia / 2.0) ** 2
        - 4.0 * params.window_long * params.window_short
    )
    mass_kg = area_mm2 * t * MATERIAL.density_g_cc / 1e6

    # Neck bending at the bend root, from the overturning moment of the hung display.
    weight_lbf = DISPLAY.weight_lbf
    bracket_lbf = mass_kg * 2.2046226218
    cg = params.magnet_standoff + t + params.spacer_len + DISPLAY.centroid_from_box_face()
    bracket_cg = params.magnet_standoff + t / 2.0
    overturning_in_lbf = (weight_lbf * cg + bracket_lbf * bracket_cg) / MM_PER_INCH
    neck_z_in3 = (params.neck_w / MM_PER_INCH) * (t / MM_PER_INCH) ** 2 / 6.0
    neck_psi = overturning_in_lbf / neck_z_in3

    # Body plate in its weak axis, VESA screw out to magnet. Effective strip = one magnet disc.
    lever_in = (params.magnet_spacing_x / 2.0 - params.vesa / 2.0) / MM_PER_INCH
    body_z_in3 = (params.magnet_disc_dia / MM_PER_INCH) * (t / MM_PER_INCH) ** 2 / 6.0
    body_psi = force_per_magnet_lbf * lever_in / body_z_in3

    # Out-of-plane deflection at the magnet, cantilever from the VESA screw. Conservative: the real
    # plate is supported at four magnets and loaded at four VESA points, so it is stiffer than this.
    force_n = force_per_magnet_lbf * N_PER_LBF
    lever_mm = params.magnet_spacing_x / 2.0 - params.vesa / 2.0
    second_moment = params.magnet_disc_dia * t ** 3 / 12.0
    deflection_mm = force_n * lever_mm ** 3 / (3.0 * E_5052_MPA * second_moment)
    # Geometric amplification out to where the finger actually is.
    screen_edge_mm = deflection_mm * (params.torsion_arm / (params.magnet_spacing_x / 2.0))

    csk_major_mm = 0.315 * MM_PER_INCH  # their M4 90 deg countersink
    csk_depth = (csk_major_mm - params.vesa_hole_dia) / 2.0  # 90 deg => half-angle 45 => depth = dr

    return Result(
        thickness_in=thickness_in,
        thickness_mm=t,
        neck_psi=neck_psi,
        neck_sf=MATERIAL.yield_psi / neck_psi,
        body_psi=body_psi,
        body_sf=MATERIAL.yield_psi / body_psi,
        magnet_deflection_mm=deflection_mm,
        screen_edge_movement_mm=screen_edge_mm,
        mass_kg=mass_kg,
        countersink_depth_mm=csk_depth,
        countersink_limit_mm=0.6 * t,
        price_usd=QUOTED_PRICE_USD.get(round(thickness_in, 3)),
    )


def _esc(s: str) -> str:
    """XML-escape label text. A bare '<' in a label makes the whole SVG unparseable."""
    return s.replace("&", "&amp;").replace("<", "&lt;").replace(">", "&gt;")


def _text(x: float, y: float, s: str, size: float = 10.0, anchor: str = "middle",
          fill: str = "#111", weight: str = "normal") -> str:
    return (f'<text x="{x:.2f}" y="{y:.2f}" font-family="Helvetica,Arial,sans-serif" '
            f'font-size="{size}" text-anchor="{anchor}" fill="{fill}" font-weight="{weight}">'
            f'{_esc(s)}</text>')
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

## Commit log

2026-08-27 Initial commit: parametric fridge-side display mount
    Generator, acceptance test, fabrication package and supporting studies for a
    magnetic-assisted hook bracket carrying a Waveshare 23.8" touch monitor on a
    Samsung RS23A500ASR counter-depth side-by-side.
    Design invariants are recorded in CLAUDE.md and are load-bearing: the hook
    carries all vertical weight, the magnets carry none, and touch torsion is the
    governing magnet load. The generator validates before it writes and refuses to
    emit a cut file that fails any check.
    As built: A36/1008 mild steel .119", 310 x 742 mm blank, one 90 deg bend,
    4 body magnets on a 246 mm square plus 6 arm magnets in three rows at
    +36/+90/+144, matte black pow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
    [bracket_flat.dxf]
2026-08-27 Measure the fridge top from photo; fix pad rule; correct hinge cover model
    The 2026-08-27 photo is a view of the LEFT SIDE PANEL, so its ruler runs
    front-to-back with zero at the rear edge. Two earlier readings treated it as a
    frontal view and invented a 213 mm ruler offset to reconcile an 8-inch
    discrepancy. The discrepancy was the tell: read as a side view, 27.5 in matches
    the 24 in case depth plus 4.6 in of door projection with no fudge at all.
    Consequences:
    - Clear window rear edge to hinge cover is 406 mm against a 190 mm arm width —
    fits with 216 mm spare. This closes the pre-order item the checklist called
    the likeliest recut risk. Modelled as hinge_cover_from_rear with a valid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
    [bracket_flat.dxf]
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2026-08-27 Fix cross-drawing disagreements found by consistency audit
    An outside audit compared every drawing against bracket_params.json. The real
    findings were numbers that disagreed between sheets:
    - assembly_drawing said 8 body magnets while assembly_drawing_27in said 4, for
    the SAME bracket. Same bug as approval_sheet: giving the optional mid-side
    positions discs made them count as fitted. Both now show 4 fitted plus a
    separate line for the positions that are cut but not fitted.
    - The approval sheet quoted 178 lbf to pull off while force_table said 146 lbf
    for the same grab — one question, two models. The sheet now uses force_table
    and names the direction, since where you grab is what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
    [bracket_flat.dxf]
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2026-08-27 Settle .188 in, correct the BOM fastener stack, publish to Pages
    Plate thickness settled at .188 in / 4.75 mm HRPO and re-quoted live at
    $197.07 (cut $112.50, +bend $126.71, +matte black). Chosen for heft and margin,
    explicitly NOT for stiffness you can feel — plate flex under a touch is 0.016 mm
    against 0.064 mm at .119 in and neither is perceptible. It is the best $/kg and
    stiffness-per-dollar in the material sweep.
    The new stack_detail drawing caught what the thickness change broke: the magnet's
    stud is a fixed 12.70 mm, so every millimetre of plate comes off the thread left
    for the nut. At 4.75 mm only a plain hex nut with NO washer still engages
    (+1.19 mm); the nylon-insert locknut a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
    [bracket_flat.dxf]
2026-08-27 Sandwich: six sourced fastener sections with bearing annuli
    Draw every combination of {nyloc, standard hex, thin/jam nut} x {washer, no
    washer} as a true section at one scale on both axes, each showing the O8.5 plate
    hole and the annulus each part actually bears on.
    Record the annulus ONCE, in engineering_report(), and derive it everywhere:
    magnet 1754 mm2 / washer 225 mm2 / bare nut 70 mm2. Fastener dimensions move
    into BracketParams beside the hole they pass through; part numbers into a
    PART_NOS dict that is None when unsourced, so a drawing says NOT SOURCED rather
    than inventing a number.
    Sourced on mcmaster.com (WebFetch returns an empty SPA shell). Two assumptions
    were wrong: the wash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
    [bracket_flat.dxf]
2026-08-27 Locking resolved: thin nyloc fits; black oxide specified
    The previous revision said no locking feature fits. That tested exactly one
    locknut -- the standard-height nylon-insert at 8.73 mm -- found it too tall, and
    generalised from a single sample. Two locking constructions fit comfortably:
    thin-profile nylon-insert 1/4 in 6.35 mm +1.60 mm 90101A122 (black)
    distorted-thread all-metal 17/64 in 6.75 mm +1.20 mm 90047A115 (plain)
    The distorted-thread nut is the SAME height as a plain hex nut, so it would have
    added locking for nothing. Threadlocker is no longer needed.
    The washer is what has to go: locking and a washer cannot both fit. That trade
    is one-sided -- the bare nut's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
    [bracket_flat.dxf]
2026-08-27 Correct washer part number; state the no-washer reasoning properly
    Caught a real error while re-examining: 96765A150 is the 3/8 in row. The 5/16 in
    black-oxide washer is 96765A145, and its thickness range is 0.040-0.060 in --
    different from the plain part's 0.035-0.065 in. Both numbers were wrong.
    That tightens rather than changes the conclusion. With the thin locknut a
    worst-case washer leaves +0.08 mm, inside the tolerance stack on three parts, so
    the washer still cannot come along. The reasoning is now stated as two
    independent points rather than one hand-wave:
    it does not fit -- and THICKNESS is what runs out, not diameter, so a larger
    washer does not rescue it
    it is not needed -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
    [generate_bracket.py, stack_detail.py]
2026-08-27 Fastener catalogue: all 39 permutations with the arithmetic shown
    Moves every nut and washer into NUTS/WASHERS catalogues in generate_bracket.py
    with a stack_permutations() generator, so the section sheet, the new matrix
    sheet and the BOM all derive from one set of rows instead of three retyped
    copies. BracketParams keeps only the STUD, which is a property of the magnet.
    New fastener_matrix.svg: 11 nut constructions x 3 washer options x with/without
    threadlocker = 39 rows, grouped fits / tolerance-stack / does-not-fit, each
    showing plate + washer + nut = needs vs stud, slack, locking type, bearing area
    and psi, and the black-oxide part number. 11 fit, 12 are marginal, 16 fail.
    stack_detail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
    [console_build.py, fastener_matrix.py, generate_bracket.py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]
2026-08-27 Specify jam nut + oversized washer + threadlocker; drop the old fridge
    CHOSEN by Charles over the mechanically-locking runner-up. A half-height jam nut
    is 1.59 mm shorter than the thinnest locknut -- almost exactly what a washer
    costs -- and threadlocker adds no height at all. That buys back the washer and
    takes the OVERSIZED one for free, because thickness is what runs out in this
    stack, not diameter:
    98514A035 jam nut, black oxide 4.76 mm
    90377A164 oversized washer O1.250 1.52 mm 732 mm2 bearing, 54 psi
    91458A115 Loctite 243, medium 0.00 mm 105 in-lbf breakaway
    11.04 mm of a 12.70 mm stud, +1.66 mm
    Bearing goes from 70 to 73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
    [bracket_flat.dxf]
2026-08-27 Fridge palette from the photo; magnet primer; consolidated review
    Fridge colour: "#dfe3e6" was hardcoded in ten modules, so recolouring was a
    ten-file edit. Now one home in bracket_common.py -- and corrected against a
    photograph of the actual unit. The side panel the bracket hangs on is a dark
    matte near-black charcoal, not the pale grey every sheet was drawing. The "ASR"
    suffix (Fingerprint Resistant Stainless) describes the DOORS only. Adds
    ON_FRIDGE_INK / ON_FRIDGE_MUTED, because annotations written for a pale fridge
    are invisible on a charcoal one; ergonomics_sweep captions converted, the rest
    still need that pass.
    magnet_primer.svg answers the question the package had no answer to: "Am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
    [bracket_flat.dxf]
2026-08-27 Work the review: one pull-off model, .188 everywhere, magnet-side fix
    Applies the approved decisions from docs/REVIEW-2026-08-27.md.
    ONE pull-off model. approval_sheet.let_go_lbf said 178 lbf, force_table said
    146, detach_study said a third set, and the page showed all of them on different
    cards. force_table is canonical; the other two are no longer called from the
    console. A comment in console_build.py had claimed this was already fixed.
    SENDCUTSEND-ORDER.md rebuilt for the 0.187 in build: thickness, bend deduction
    (0.1955 -> 0.3225 in), inside radius, blank, neck, magnet spacing, stress
    margins and the standoff, which appeared as both "6 mm" and "8 mm" in one
    section when it is 11.51. Th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
    [bracket_flat.dxf]
2026-08-27 Count the magnets in the hanging load; label every weight figure
    The load the hook carries was computed from the PLATE AREA ONLY. Eight O48 x
    11.51 mm pot magnets are bolted to that plate and hang off it, and they weigh
    1.27 kg -- so the hanging load was understated by ~13%, and every stress margin
    derived from it with it. Now counted, along with the nuts and washers:
    screen 3.94 kg 8.69 lb
    steel plate 5.81 kg 12.80 lb
    magnets 1.27 kg 2.79 lb <- was missing
    nuts/washers 0.10 kg 0.21 lb
    TOTAL 11.11 kg 24.50 lb (was 9.75 kg / 21.5 lb)
    Magnet mass is DERIVED from the disc envelope at an assumed 7.6 g/cc for a
    steel-cupped neodymium pot; M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
    [approval_sheet.py, console_build.py, display_compare.py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]
2026-08-27 Consistent pad/magnet depiction; two drawing bugs fixed
    A sweep of all 20 sheets for one question -- does the bracket ever touch the
    fridge, and is the gap filled with the pad and magnets that actually hold it off
    -- found two real errors and a split visual vocabulary.
    approval_sheet drew the ARM MAGNETS SUNK INTO THE FRIDGE: FH - standoff -> FH,
    i.e. below the top surface, putting them on the far side of the steel from the
    pad beside them, so the two could never read as the same height. They belong in
    the gap the pad holds open: FH -> FH + standoff.
    variant_compare held the spine gap open and left it as bare white air -- no
    magnets, no pad, down the whole side. A drawing that leaves that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
    [bracket_flat.dxf]
2026-08-27 Remove crown entirely; write "lb" not "lbf" for readers
    CROWN. The original brief's fridge had a single formed steel wrapper, which
    domes, so the pad budget carried a "crown rise under the arm" term that stacked
    with the corner-radius lift. The Samsung's top was straightedged and
    photographed FLAT, and the term has been zero ever since. A parameter that is
    provably zero -- plus its function, its contribution to the budget, and a whole
    explanatory sheet built around it -- is drift waiting to happen: someone re-reads
    the pad budget in a year and re-derives a dome that does not exist.
    Gone from generate_bracket (crown_rise, crown_rise_at, the budget term),
    reach_matrix, variant_compare, CLAUDE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
    [bracket_flat.dxf]
2026-08-27 Verify the weights against source; count the foam
    Checked rather than assumed, after the numbers were challenged.
    DISPLAY 3.94 kg is CONFIRMED at source (docs.waveshare.com/23.8inch_FHD_Monitor).
    Caveat recorded: Waveshare do not state whether that includes the stand. If it
    does, the figure is conservative, since the stand comes off for VESA mounting.
    STEEL PLATE 5.81 kg re-derived by hand and it holds: the part is an L, not the
    bounding box -- body 96,100 mm2 plus a 190 mm wide neck/arm of 81,474, less the
    O90 vent and 14 windows, is 155,772 mm2 at 4.7498 mm and 7.85 g/cc. The 31 holes
    (1,166 mm2, ~43 g) are deliberately NOT subtracted.
    FOAM was missing: ~0.20 kg of sponge across the arm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
    [bracket_flat.dxf]
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2026-08-27 Work the visual defect list; one of them was a data bug
    magnet_pattern_study was drawing an 8-magnet layout that cannot be built. The
    second row was hardcoded at y = 75 and 225, which is 43 mm from the corner row
    at inset 32, against a hard floor of disc + 6 = 54.02 mm. The discs overlapped
    by 5 mm, so the sheet made a valid idea look impossible. Now DERIVED from the
    floor: y = 86.02 and 223.98.
    Text and layout fixes, each with the cause noted in the source:
    stack_detail footer line escaped its box and clipped at the canvas edge;
    long panel titles overprinted the right-aligned slack badge.
    Titles now shrink to the space the verdict leaves.
    ergonom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
    [bracket_flat.dxf]
2026-08-27 Second pass on the visual defects, including three I caused
    A verification pass rendered all 20 sheets and checked each fix. Eight of
    fourteen held; six did not, and three of the failures were introduced by the
    first pass rather than pre-existing.
    Introduced by me, now fixed:
    stack_detail the new footer line landed on the pre-existing one at +82;
    both unreadable. Moved to +100, box grown.
    magnet_primer end-anchoring the arm label ran it off the LEFT canvas edge.
    Start-anchored from the card margin instead.
    approval_sheet moving the clear-window dimension out from under the header
    put it through the black neck rectangle. It sp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
    [approval_sheet.py, arm_width_sweep.py, assembly_drawing.py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]
2026-08-27 Third visual pass: fix the causes, not the symptoms
    The second verification found 6 of 9 held and 3 broke again. Every failure was
    the same two root causes, so this pass fixes those rather than nudging labels.
    DRAW ORDER. A panel behind text is worthless if later drawing paints over it.
    The assembly Pi-fan label had a panel and was still struck through by the
    REAR BOX dimension, the plate edge and the display outline -- all emitted after
    it. The label and its panel now come after the dimensions block. force_table's
    AS BUILT tag had already moved once for the same reason and landed on the first
    data cell; it now sits under the last rule, the only clear space in its column.
    DERIVED POSITIONS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
    [bracket_flat.dxf]
2026-08-27 Fourth visual pass: the last three, and a rule I had mis-stated
    Third verification: 6 of 7 held. The three remaining were all mine.
    The assembly Pi-fan label was moved after "the dimensions" and I did not check
    what "the dimensions" actually meant -- three more followed, including the
    vertical REAR BOX one that was cutting through it. Now emitted as the last thing
    on the elevation, verified by counting drawing primitives after it: 0 lines.
    bracket_preview's "MEASURE THIS" was still dark crimson on the charcoal fridge.
    It is the one instruction on that sheet the reader is meant to act on, and it
    was the least visible thing on it.
    The third is a correction to the rule itself. ON_FRIDGE_* wa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
    [bracket_flat.dxf]
2026-08-28 Fifth pass: the last two nits, and draw order for a third time
    Fourth verification came back clean -- all three fixes held, no regressions,
    verdict presentable. These are the two cosmetic items it listed as optional.
    approval_sheet's callout leaders. The ann() docstring has claimed this was fixed
    since it was written; it never was for a two-line caption, and fixing that
    revealed the real problem: clearing a callout's OWN leader is not enough,
    because the NEXT callout's leader is drawn afterwards and runs straight across
    the previous one's text. ann() now returns leader and label separately, every
    leader is laid down first, and all three labels go on top. Verified by render,
    not by reasoning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
    [approval_sheet.py, assembly_drawing.py]
2026-08-29 Alternate concept: floor-standing slotted strut
    Explores standing a slotted strut channel on the floor and running it up the
    side panel, instead of hooking over the top. New module channel_concept.py ->
    channel_concept.svg, registered on the page as a STUDY, bannered ALTERNATE
    CONCEPT so it cannot be mistaken for the design of record.
    Channel is McMaster 3310T791, low-profile slotted strut, BLACK powder-coated,
    which happens to be what the side panel is. 5 ft is $30.26 and 1.94 kg against
    $197.07 for the bracket. Section properties are DERIVED from the published
    dimensions -- McMaster do not publish I or Z for this profile -- so they carry
    the error of an estimated return lip.
    Three findin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
    [channel_concept.py, console_build.py]
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2026-08-29 Concept sheet rebuilt for the two-strut bent-foot design
    Supersedes the single-strut sketch. Two 6 ft struts at 246 mm centres tied by
    one bent foot that slides under the fridge and is wedged so the appliance's own
    weight bears on it.
    The wedge is quantified rather than asserted: at a 200 mm tail it needs 33 lb on
    the foot, 15% of the appliance. That is a modest fraction, but how hard someone
    drove a wedge is not a designable quantity, so it is BACKUP -- the magnets carry
    the case alone at 49x, in pull.
    Records the division that matters: the foot gives STABILITY, the magnets give
    STIFFNESS, and they do not substitute. Tying the strut bases does nothing for
    sway because the pull load is out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
    [channel_concept.py]
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2026-08-31 Concept sheet for the assembly as decided
    New concept_sheet.py -> concept_sheet.svg, in this repo rather than the old one,
    because this is where the design lives now.
    Everything derives from an Assembly dataclass, which is the single home for the
    dimensions -- gap, washers, display face and the unavoidable remainder are all
    computed, not typed. If the sheet and the brief ever disagree, the sheet is what
    was actually run.
    Shows: side elevation with both clamps, the outboard foot the strut stands on,
    and the plate; what holds it and with how much margin; the two parts and how the
    carriage-bolt stud avoids any welding; the assembly sequence; and the three
    things still needing a torch under th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
    [concept_sheet.py]
2026-08-31 Elevator bolt, not carriage; and draw the base joint
    Charles: the head faces the fridge, so a domed carriage head is the wrong shape
    there. He is right, and not marginally.
    5/16-18 elevator: head 30.16 mm diameter x 2.78 mm thick and FLAT, against a
    carriage bolt's 19.81 x 5.08 dome. At 2.78 the head hides inside the 3 mm foam
    and never touches the panel; the carriage dome stands 2.08 mm proud of the same
    foam and presses a hard point on appliance sheet. Bearing area 715 mm2 against
    308, so 2.3x. Same square neck, so it still cannot spin, and still no welding.
    Caught while reading the dimensions: the square neck is 4.83 mm long against a
    3.02 mm clamp leg, so it passes 1.80 mm beyond. The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
    [concept_sheet.py]
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2026-08-31 Correct the joint: the nut belongs INSIDE the channel
    Charles spotted it on the drawing. The slots are in the strut's BACK WEB, so the
    bolt passes through that web and the nut bears on its inside face. I had drawn
    the bolt running clean through the channel and nutted outside the open face.
    Two things wrong with that. It is a much longer bolt than needed -- the material
    is only clamp 3.02 + foot 3.02 + web 1.78 = 7.83 mm, so 3/4 in would do and 1 in
    is comfortable. And it puts the nut exactly where the PLATE's channel nuts have
    to live; the open face has to stay clear for them.
    Drawing corrected: nut inside the channel, return lips shown, open face labelled
    as the plate's. Three more render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
    [concept_sheet.py]
2026-08-31 Put the lower clamp below the fridge, and draw the base properly
    Charles: the lower clamp was oddly intersecting the fridge's bottom. It was --
    its corner sat at 120 mm while the cabinet's underside was drawn at an invented
    70. Both now come from base_gap, the MEASURED 10-20 mm, taken as 15. The clamp's
    long leg tucks under the cabinet and its short leg rises outside it.
    But at side-elevation scale that whole arrangement is about 3 px, so seeing it
    was impossible. Adds THE BASE at 3.1x in elevation: floor, foot, strut standing
    on it, clamp long leg under the cabinet with its foam, clamp short leg rising
    outside, and the underside dashed and dimensioned.
    Also fixes the third instance of the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
    [concept_sheet.py]
2026-08-31 Pad under the outboard foot
    Charles: steel on wood will not be good over time. Right, and the reason is not
    the one the numbers suggest -- static pressure is under 3 psi and nothing is
    being crushed. It is that the foot's laser-cut EDGES line-load a floor that is
    not perfectly flat, that grit trapped beneath turns the foot into an abrasive,
    and that this assembly sits unmoved for years rather than being shuffled about.
    The constraint worth writing down: the pad has to GRIP as well as protect, which
    rules out the obvious choice. Felt is the standard furniture answer and it is
    wrong here -- it would let the assembly slide, and sliding is the one failure
    this design has no other defence agains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
    [concept_sheet.py]
2026-08-31 Combine both designs on one page; repo renamed fridge-display-mount
    The repo was named for a mechanism that is no longer the design. Renamed to
    fridge-display-mount, which names the PROBLEM rather than one answer to it, so
    the next change of approach does not need another rename.
    The page now carries both designs and says which is which:
    A new "Two designs" section leads the page. CURRENT is the clamped strut --
    two low-profile struts, clamped top and bottom, standing on the floor, no
    magnets. PREVIOUS is the hook, and it is described as FINISHED and superseded
    for adjustability and floor loading, NOT for being wrong.
    The diagram groups are relabelled so nothing is ambiguous: "C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
    [console_build.py]
2026-08-31 Add the clamp design's drawing set; derive part width; re-datum the strut centre
    Six sheets so the clamped strut is documented to the same standard the magnet
    hook was: approval, flat patterns, assembly order, hinge clearance, load path,
    and a slot-vs-clamp-height validation.
    Two real findings came out of drawing them rather than describing them.
    THE STRUTS CANNOT BE CENTRED ON THE CASE DEPTH. That is the obvious choice and
    it drives the front clamp 51.2 mm INTO the hinge cover. The clear window is the
    only space that actually exists, so it is now the datum: strut_centre is
    derived from it, and the cost is cosmetic -- the screen sits 102 mm behind the
    case centre, still well with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
    [clamp_sheets.py, concept_sheet.py]
2026-08-31 Separate the two designs on the page; add the clamp drawing set
    The page mixed both designs together, so it was not clear what was actually
    being proposed. Three things caused that, and all three are fixed.
    channel_concept.svg -- the FIRST DRAFT of the clamped strut -- was filed under
    the magnet design labelled "ALTERNATE". Two different strut designs on one
    page with nothing saying which was live. Deleted; it stays in git history.
    The diagram groups are now CURRENT DESIGN, APPLIES TO BOTH, and PREVIOUS
    DESIGN. The four sheets that survive the change of load path -- ergonomics,
    orientation, 23.8-vs-27, and the magnet primer -- were scattered through the
    magnet groups and now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
    [console_build.py]
2026-08-31 Spanning clamp bars: tie the two struts into a frame
    Charles asked whether wider feet and clamps increase rigidity. Mostly no, and
    the reasoning is worth recording because it is counter-intuitive.
    Each clamp bolts to ONE strut, so widening it adds steel that is not tied to
    anything at its far end. The couple that resists twist is the STRUT SPACING
    (246 mm) and part width does not change it. Widening only buys local stiffness:
    the strut rotating about its own bolt, and a slightly bigger floor footprint.
    The two levers that move global rigidity are widening the spacing -- capped at
    about 285 mm by the PLATE, which must reach both struts while hiding behind a
    325 mm portrait display, so only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
    [clamp_sheets.py, concept_sheet.py]
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
